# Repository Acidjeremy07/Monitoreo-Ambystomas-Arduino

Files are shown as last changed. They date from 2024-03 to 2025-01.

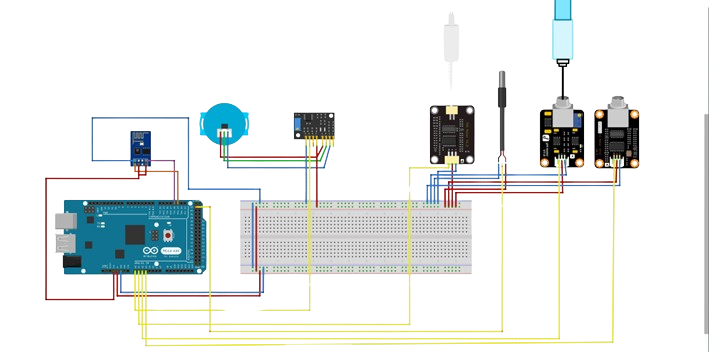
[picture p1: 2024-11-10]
Expo TT1/PNG de reporte técnico/PNG esquemático fritzing.png

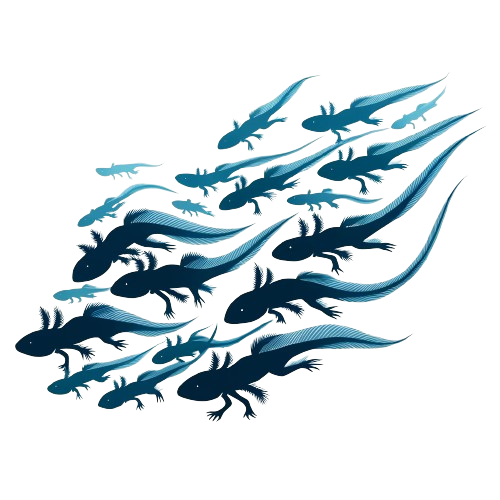
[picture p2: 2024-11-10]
Expo TT1/PNG Ajolotes/Ajolotes Adultos.png

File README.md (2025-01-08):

# Monitoreo Ambystomas arduino
 TT de monitoreo de la especies ambystomas tomando en cuenta el monitoreo de la calidad del agua donde se encuentran de manera ex situ
 Dentro del presente repositorio tenemos lo que es la forma de calibrar cada sensor así como la forma de usarlo de manera 
 individual, esto esta organizado por cada sensor de tal manera que se puede hayar cada código del sensor por carpeta con su nombre
 correspondiente

 Se incluye los primeros diseños de PCB para la conexión entre el arduino mega, esp01 y los sensores en la carpeta PCB

 Dentro de Datasheet's se incluye la hoja de datos de cada sensor y una referencia de conexión con el esp01

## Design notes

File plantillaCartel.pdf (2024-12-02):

Introducción (incluye planteamiento del problema, hipótesis y justificación)
El presente trabajo muestra la implementación de un sistema de monitoreo de la calidad del agua en ajolotarios dedicados a la conservación ex-situ de especies del género Ambystoma, en peligro de extinción o bajo protección especial (PROCER, 2018). El sistema cuantifica el valor de los parámetros esenciales para la supervivencia de los ajolotes como lo es el oxígeno disuelto y, si alguno alcanza niveles perjudiciales, notifica a los responsables mediante dispositivos móviles para una respuesta inmediata. Además de incluir un sistema web para el registro que se lleva cada treinta minutos y en caso de una alerta sea aproximadamente al cambio en el ajolotario , almacenamiento histórico de datos y la visualización e interpretación de los datos crudos, ya que esto complementaría y mejoraría la toma de decisiones en un ajolotario.

Materiales y métodos
Para el desarrollo del sistema de monitoreo de la calidad del agua en los ecosistemas del ajolote, se empleará una tarjeta Arduino Mega 2560 conectada a varios sensores que miden diferentes parámetros de calidad del agua. Los sensores utilizados son:
•Sensor de pH
•Sensor de Oxígeno Disuelto (mg/L)
•Sensor de Temperatura (°C)
•Sensor de Sólidos Disueltos Totales (TDS, ppm
•Sensor de Sólidos Suspendidos Totales (TSS, NTU)
La tarjeta Arduino se conectará a un módulo Wi-Fi ESP-01, que permitirá el envío de datos a la nube mediante Azure IoT. Para la arquitectura del sistema, se implementará un modelo de publicador-suscriptor, facilitando la comunicación entre los dispositivos de monitoreo y el servidor en la nube.
En el servidor, se usará un patrón de arquitectura de software de modelo-vistacontrolador (MVC), configurado como una API-REST para recibir y procesar los datos. La plataforma de alojamiento y administración de la base de datos será Vercel, donde se desplegará una aplicación web progresiva (PWA). Esta PWA permitirá visualizar los datos de calidad del agua tanto en dispositivos móviles como en equipos de cómputo, además de enviar alertas a través de WhatsApp en caso de detectar variaciones críticas en los parámetros monitoreados.

Referencias

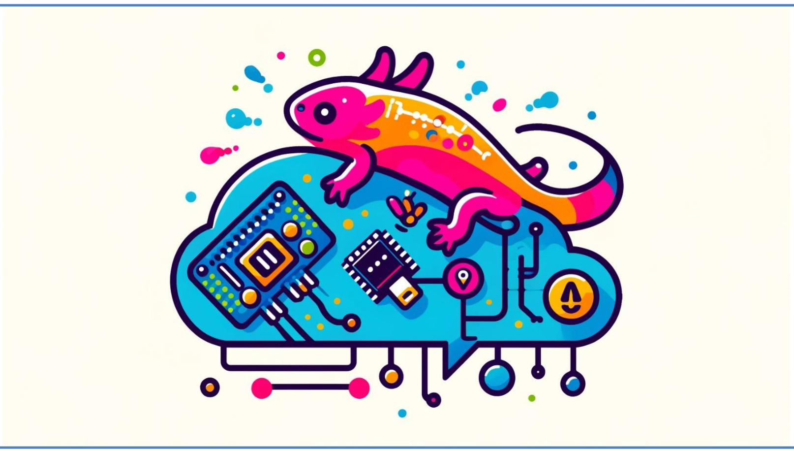
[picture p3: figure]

Comisión Nacional de Áreas Naturales Protegidas. (s/f).

Programa de Conservación de Especies en Riesgo (PROCER).

gob.mx. Recuperado el 12 de noviembre de 2024, de

https://www.gob.mx/conanp/acciones-y-

programas/programa-de-conservacion-de-especies-en-riesgo/ (https://www.gob.mx/conanp/acciones-y-programas/programa-de-conservacion-de-especies-en-riesgo/)

Objetivos
Implementar un sistema de gestión de datos que promueve la mejora continua para la conservación y bienestar de la especie Ambystoma mexicanum:
- Diseñar un dispositivo de obtención y envío de datos de los parámetros del ajolotario (Arduino MEGA 2560) .
- Construir un gabinete impermeable para PCB al que va conectado Arduino.
- Elaborar una aplicación web progresiva.
- Implementar un sistema de alertamiento en caso de detectar parámetros dañinos en el agua para los ajolotes.

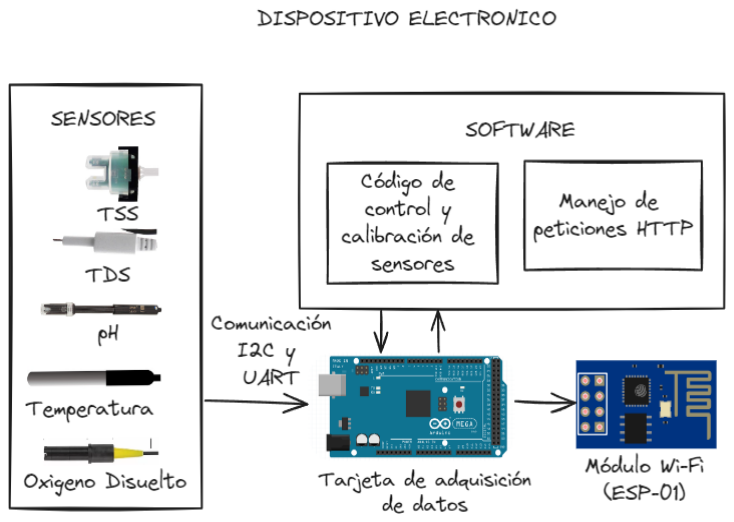
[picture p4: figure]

Resultados y conclusión
La implementación del sistema de monitoreo de la calidad del agua en el ajolotario Axolocali ha tenido efectos muy positivos sobre la conservación y manejo de los ajolotes en cautiverio. Al permitir la medición precisa de parámetros fisicoquímicos del agua, como el oxígeno disuelto, la temperatura, el pH, los sólidos disueltos y los sólidos suspendidos, el sistema evita la intervención directa en el entorno de los ajolotes, reduciendo así el estrés y el riesgo de alteraciones en su hábitat, lo cual es crucial para esta especie en peligro de extinción.
El registro y almacenamiento continuo de datos en la nube ha facilitado una interpretación más rápida y precisa de las condiciones del agua, lo que permite una toma de decisiones informada por parte de los cuidadores. Esto asegura una respuesta inmediata a cualquier cambio crítico en los parámetros, previniendo condiciones adversas para los ajolotes.

En consecuencia, el sistema ha demostrado ser una herramienta eficaz para la conservación ex-situ de especies del género Ambystoma. Dados los resultados exitosos en Axolocali, se proyecta la posibilidad de implementar este sistema en otros ajolotarios del país, contribuyendo a la protección y preservación de esta especie en riesgo a nivel nacional.

Representación

visual del sistema
de monitoreo .

## SISTEMA DE MONITOREO DE PARÁMETROS FISICOQUÍMICOS DE CALIDAD DEL AGUA PARA LA CONSERVACIÓN EX-SITU DE ESPECIES DE GÉNERO AMBYSTOMA

INSTITUTO POLITECNICO NACIONAL ESCUELA SUPERIOR DE CÓMPUTO BUCIO BARRERA OSCAR DANIEL, CAZARES CRUZ JEREMY SAJID, GUERRERO PÉREZ BRANDON JOSUÉ bguerrerop1600@alumno.ipn.mx

Tarjeta de adquisición de datos

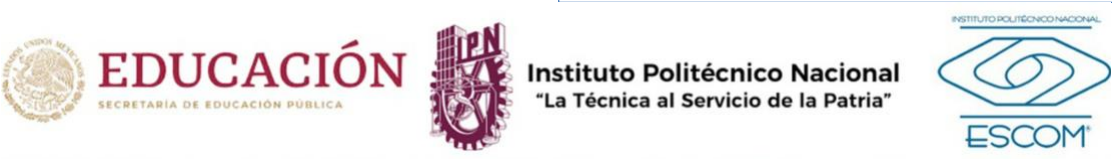
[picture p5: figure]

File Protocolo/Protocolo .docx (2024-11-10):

Prototipo para el monitoreo y alertamiento de la calidad del agua a través del internet de las cosas para conservación de especies ambystomas.

Trabajo Terminal No. 2024-B

Alumnos: Cazares Cruz Jeremy Sajid, *Guerrero Pérez Brandon Josué

Director: Morales Rodriguez Ursula Samantha

Email: bguerrerop1600@alumno.ipn.mx

Resumen - Se presenta el desarrollo de un ajolotario el cual contará con la innovación de mostrar la información de la calidad del agua en todo momento facilitando la comprensión de esta información a los clientes, esto con la finalidad de asegurar la supervivencia de los ajolotes manteniendo un hábitat óptimo para la conservación de estos.

Palabras clave - Sensores, calidad del agua, Internet de las cosas.

1. Introducción

La calidad del agua es fundamental para el bienestar de los ajolotes que son criaturas endémicas del Valle de México. Estos animales son especialmente sensibles a toxinas y cambios en su entorno acuático por lo que tener una mala calidad del agua afecta su salud, comportamiento y capacidad de regeneración.

Para abordar este desafío, la tecnología moderna, como el Internet de las Cosas (IoT), se ha convertido en una herramienta valiosa en la conservación de los ajolotes. Dispositivos inteligentes conectados a través de la IoT monitorean constantemente parámetros críticos como el pH, la temperatura y la salinidad del agua en los hábitats de los ajolotes. Estos dispositivos alertan a los cuidadores sobre cualquier desviación de los niveles óptimos y, en algunos casos, pueden ajustar automáticamente las condiciones para mantener un ambiente saludable.

Por ejemplo, sensores instalados en laboratorios de investigación o en hogares de entusiastas pueden enviar datos en tiempo real a aplicaciones móviles o plataformas en línea. Esto asegura un monitoreo constante y permite una respuesta inmediata ante cualquier problema, garantizando así la salud de los ajolotes.

La aplicación de la IoT en la conservación de ajolotes es un ejemplo de cómo la tecnología puede ser utilizada para proteger la biodiversidad y preservar especies en peligro de extinción. Esta combinación de prácticas tradicionales de cuidado con innovaciones del siglo XXI demuestra cómo podemos aprovechar la tecnología para proteger a estas fascinantes criaturas y su frágil hábitat.

A pesar de contar con el internet de las cosas, en el ámbito del cuidado de los animales acuáticos no siempre se visualiza el panorama completo, es decir que no se toman en cuenta todos los factores que favorecen a la supervivencia de los animales acuáticos, un ejemplo de esto es que casi no hay empresas que midan el oxígeno disuelto que hay en el agua.

En la siguiente tabla se colocan algunas empresas que si llevan a cabo el cuidado de hábitats de animales acuáticos:

EMPRESA | CARACTERÍSTICAS
HANNA instruments | Cuentan con sistemas embebidos listos para mostrar con que calidad cuenta el agua (en sus diferentes parámetros) con solo tener una muestra de esta.
Loxone | Ofrecen un acuario automático, el cual controlará la temperatura, verificará el nivel del agua, la iluminación y la alimentación de la pecera.

2. Objetivo

Implementar un prototipo para el monitoreo y alertemiento

2.1 Objetivos específicos

- Diseñar un circuito que integre sensores de pH y temperatura, capaces de detectar y registrar cambios con precisión.
- Diseñar un recinto o caja impermeable para albergar el circuito y asegurarse de que no haya ningún riesgo para los ajolotes.
- Programar un microcontrolador para leer los datos de los sensores y transmitirlos en tiempo real a una plataforma de IoT.
- Integrar conectividad al microcontrolador para transmitir los datos.
- Desarrollar una aplicación o interfaz web que permita visualizar en tiempo real los datos de pH y temperatura
- Establecer un sistema de notificaciones que alerte al usuario cuando la temperatura esté fuera del rango de 14°C a 20°C.
- Configurar alertas si el pH detectado si se desvía significativamente del valor aceptable.
3. Justificación

El proyecto de desarrollar un medidor de pH y temperatura para el agua en un hábitat de ajolotes es de suma importancia. Los ajolotes (Ambystoma mexicanum) son anfibios en peligro de extinción, y la conservación de su hábitat y bienestar es crucial para su supervivencia.

La monitorización constante y precisa del pH y la temperatura del agua es esencial para garantizar el bienestar de los ajolotes en cautiverio. Variaciones fuera de los parámetros óptimos pueden causar estrés, enfermedades e incluso la muerte de estos animales. La intervención manual y frecuente, que ha sido la práctica tradicional, es tediosa y puede llevar a periodos sin supervisión, lo que aumenta el riesgo para los ajolotes.

La incorporación de la tecnología de Internet de las Cosas (IoT) en este proyecto es fundamental. Al utilizar sensores conectados en tiempo real a plataformas digitales, se asegura un monitoreo continuo y se reciben alertas inmediatas en caso de problemas en las condiciones del agua. Esto no solo mejora el cuidado de los ajolotes, sino que también facilita la labor de los cuidadores y reduce el riesgo de errores humanos.

Además, este proyecto tiene un valor educativo significativo. Al proporcionar datos en tiempo real y una plataforma digital, se puede educar a cuidadores y entusiastas sobre la importancia crítica de mantener los niveles de pH y temperatura adecuados para los ajolotes. Al compartir esta información, se crea conciencia sobre la delicada situación de esta especie y se promueve su conservación.

4. Productos o Resultados esperados

Dispositivos de monitoreo IoT: Equipos diseñados específicamente para estanques y acuarios de ajolotes, capaces de rastrear condiciones como el pH, la temperatura y otros factores vitales del agua en tiempo real.

Aplicación web: Una plataforma digital accesible para los cuidadores que muestre de manera clara e intuitiva los datos recogidos por los dispositivos. Esta aplicación podría ofrecer gráficos de tendencias, alertas y recomendaciones basadas en las condiciones actuales.

Sistema de alerta automático: Un sistema que notifique de manera inmediata a los responsables cuando las condiciones del agua se desvíen de los parámetros ideales, garantizando intervenciones rápidas para salvaguardar el bienestar de los ajolotes.

Aplicación móvil: Una plataforma digital accesible desde cualquier dispositivo movil para los cuidadores que muestre de manera clara e intuitiva los datos recogidos por los dispositivos. Esta aplicación podría ofrecer gráficos de tendencias, alertas y recomendaciones basadas en las condiciones actuales.

5. Metodología
6. Cronograma
7. Referencias

[1] https://www.oracle.com/mx/internet-of-things/what-is-iot/

[2] https://cvsauces.com/cuidados-del-ajolote/

[3] https://www.badgermeter.com/es-us/monitoreo-de-la-calidad-del-agua/

[4] https://obtienearchivo.bcn.cl/obtienearchivo?id=repositorio/10221/23747/2/Calidad%20del%20Agua%20Final.pdf

[5] https://hannainst.com.mx/medidores-para-acuarios/

[6] Acuario automático - Ejemplos prácticos Loxone (https://www.loxone.com/eses/kb/acuario-automatico/)

8. Alumnos y Directores

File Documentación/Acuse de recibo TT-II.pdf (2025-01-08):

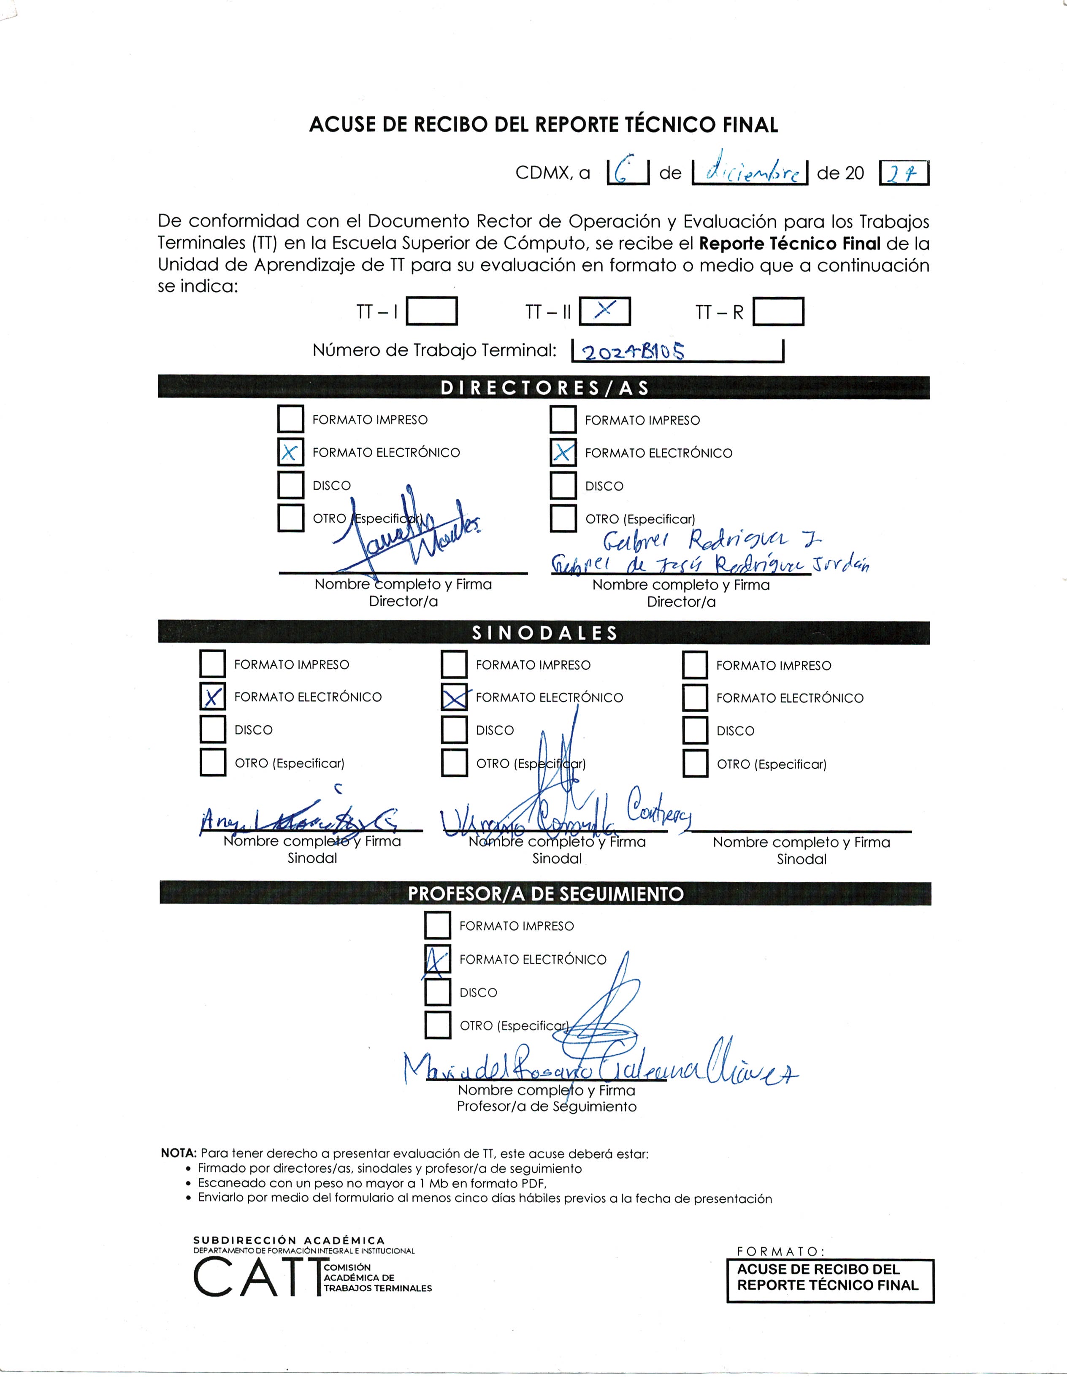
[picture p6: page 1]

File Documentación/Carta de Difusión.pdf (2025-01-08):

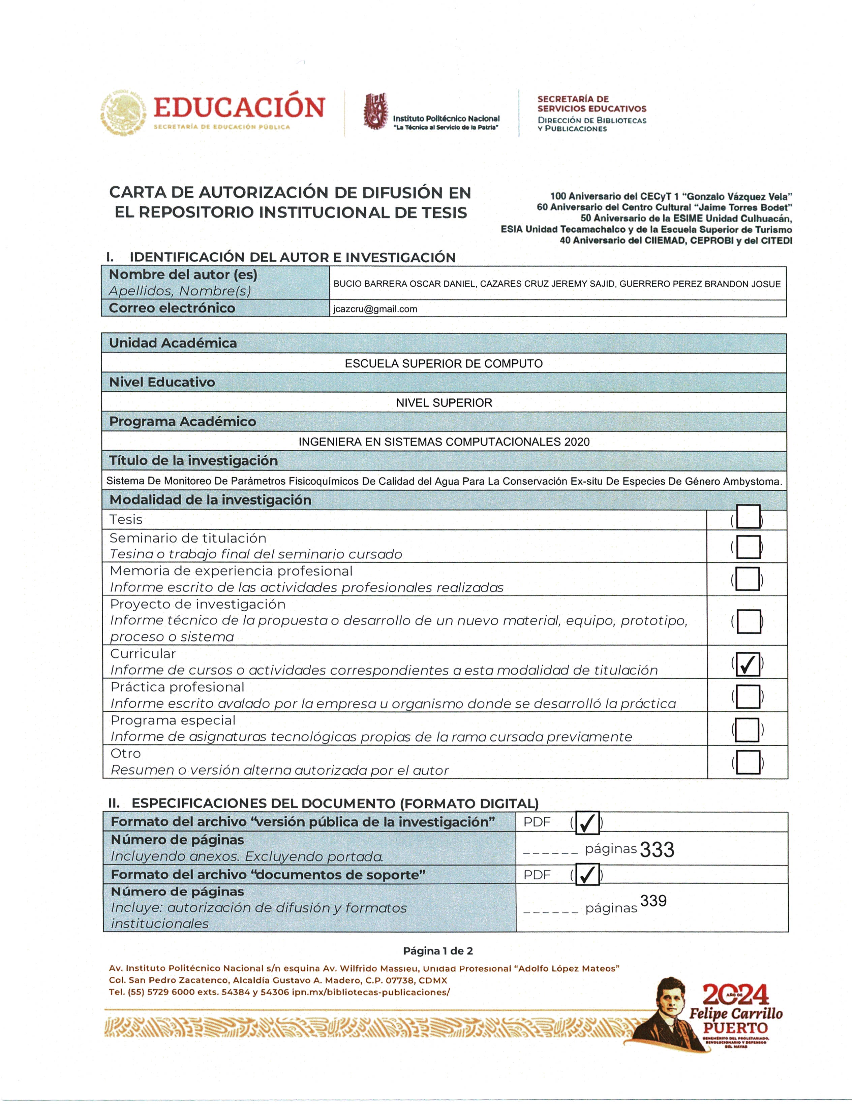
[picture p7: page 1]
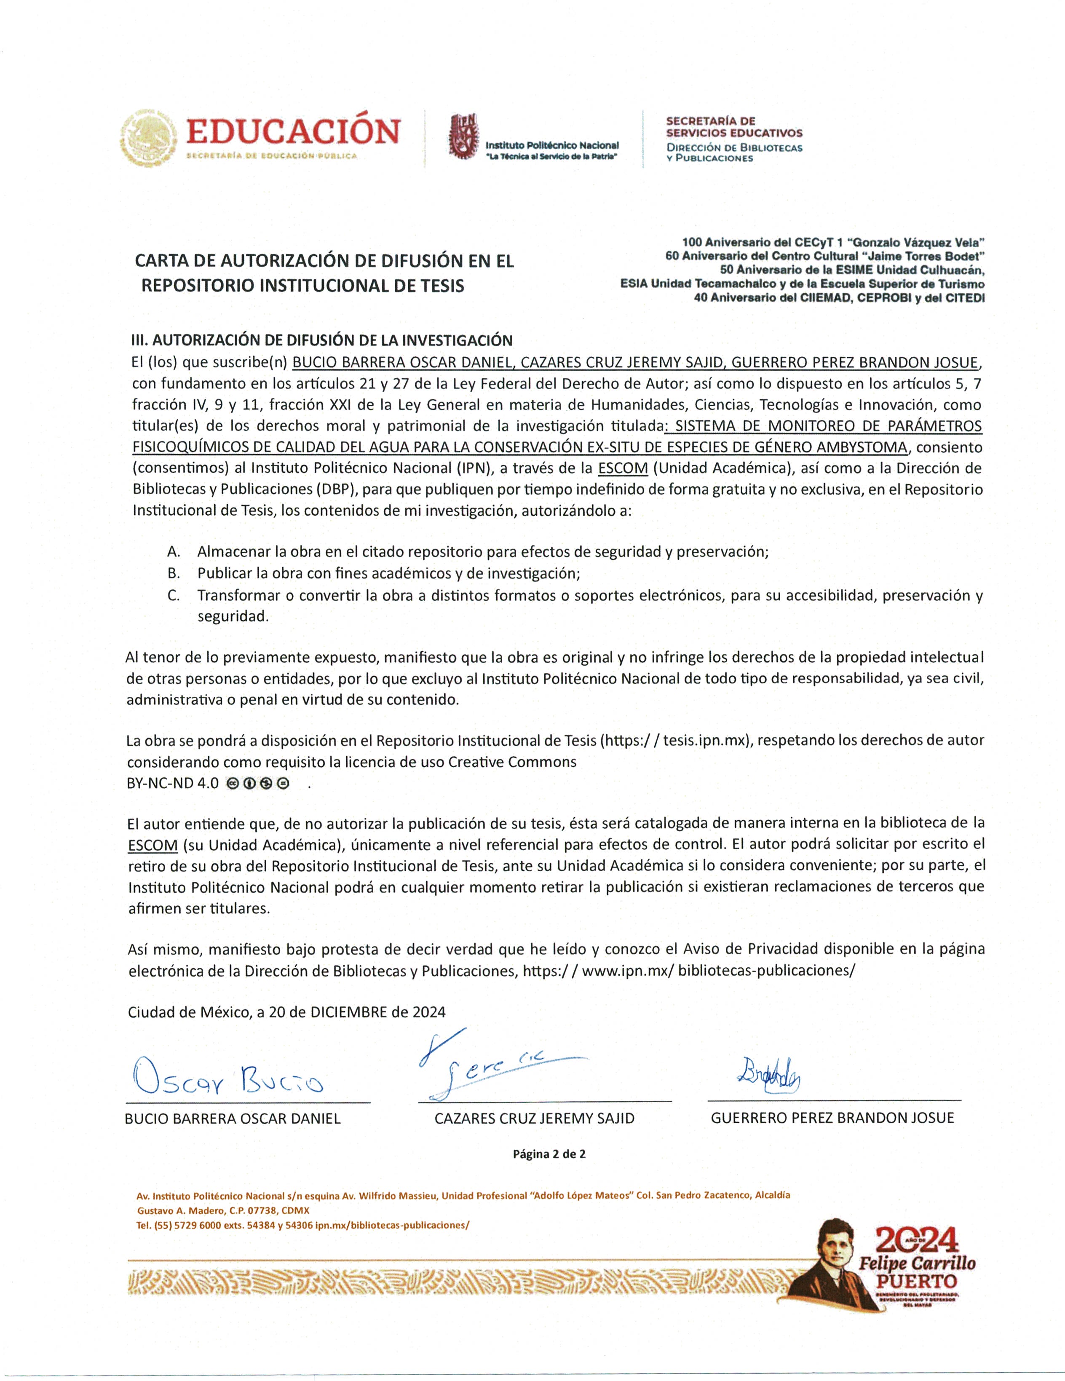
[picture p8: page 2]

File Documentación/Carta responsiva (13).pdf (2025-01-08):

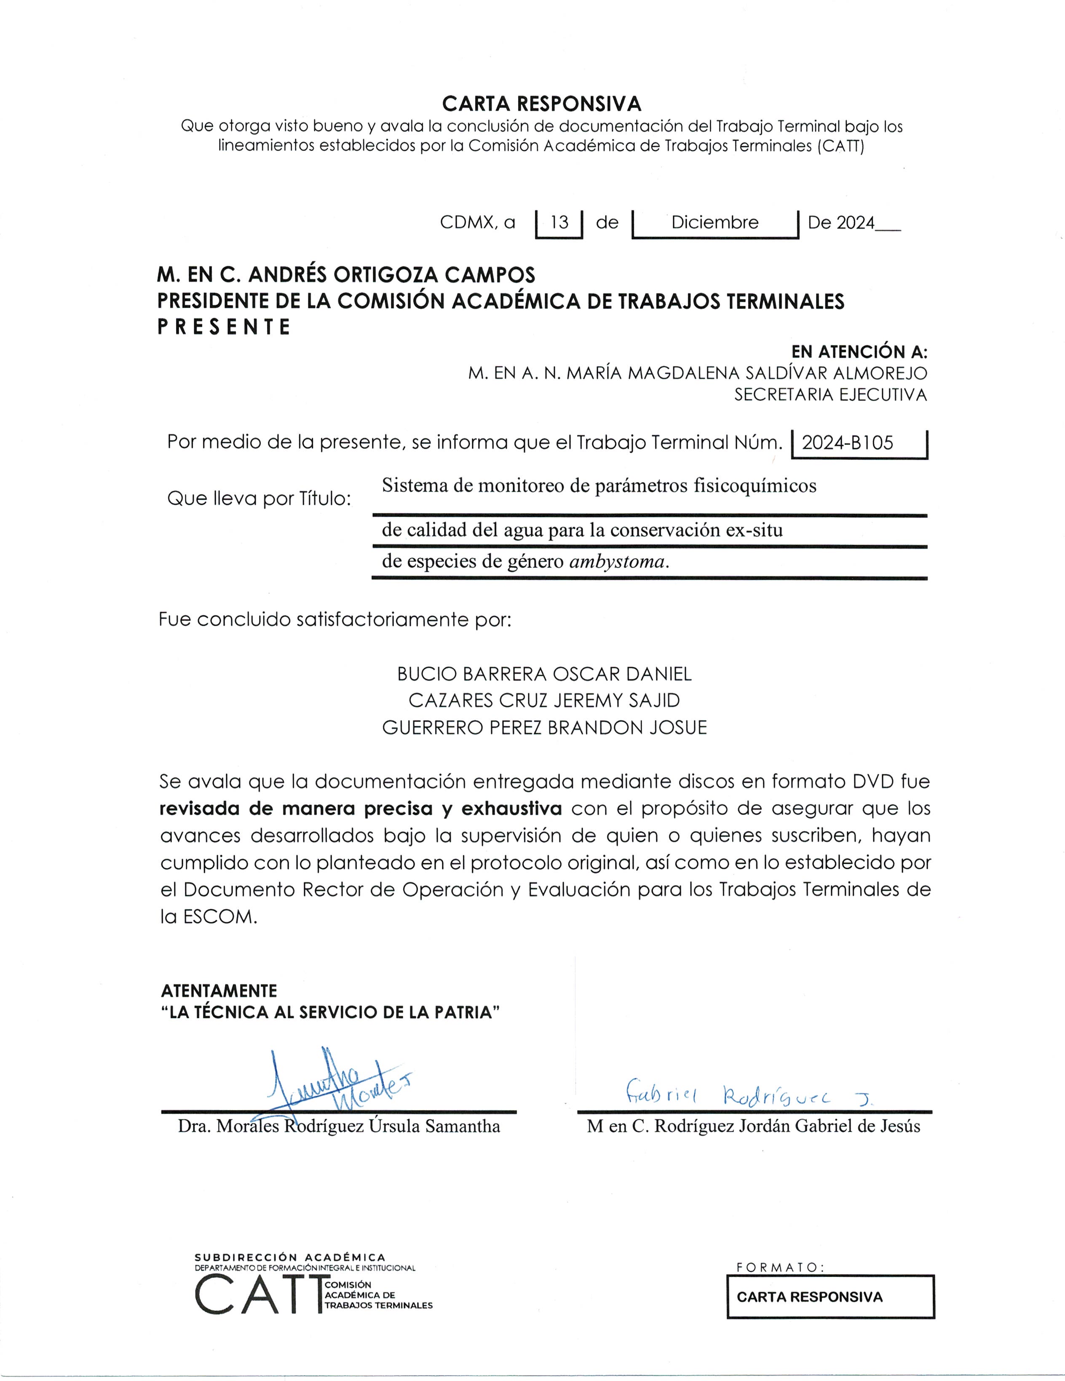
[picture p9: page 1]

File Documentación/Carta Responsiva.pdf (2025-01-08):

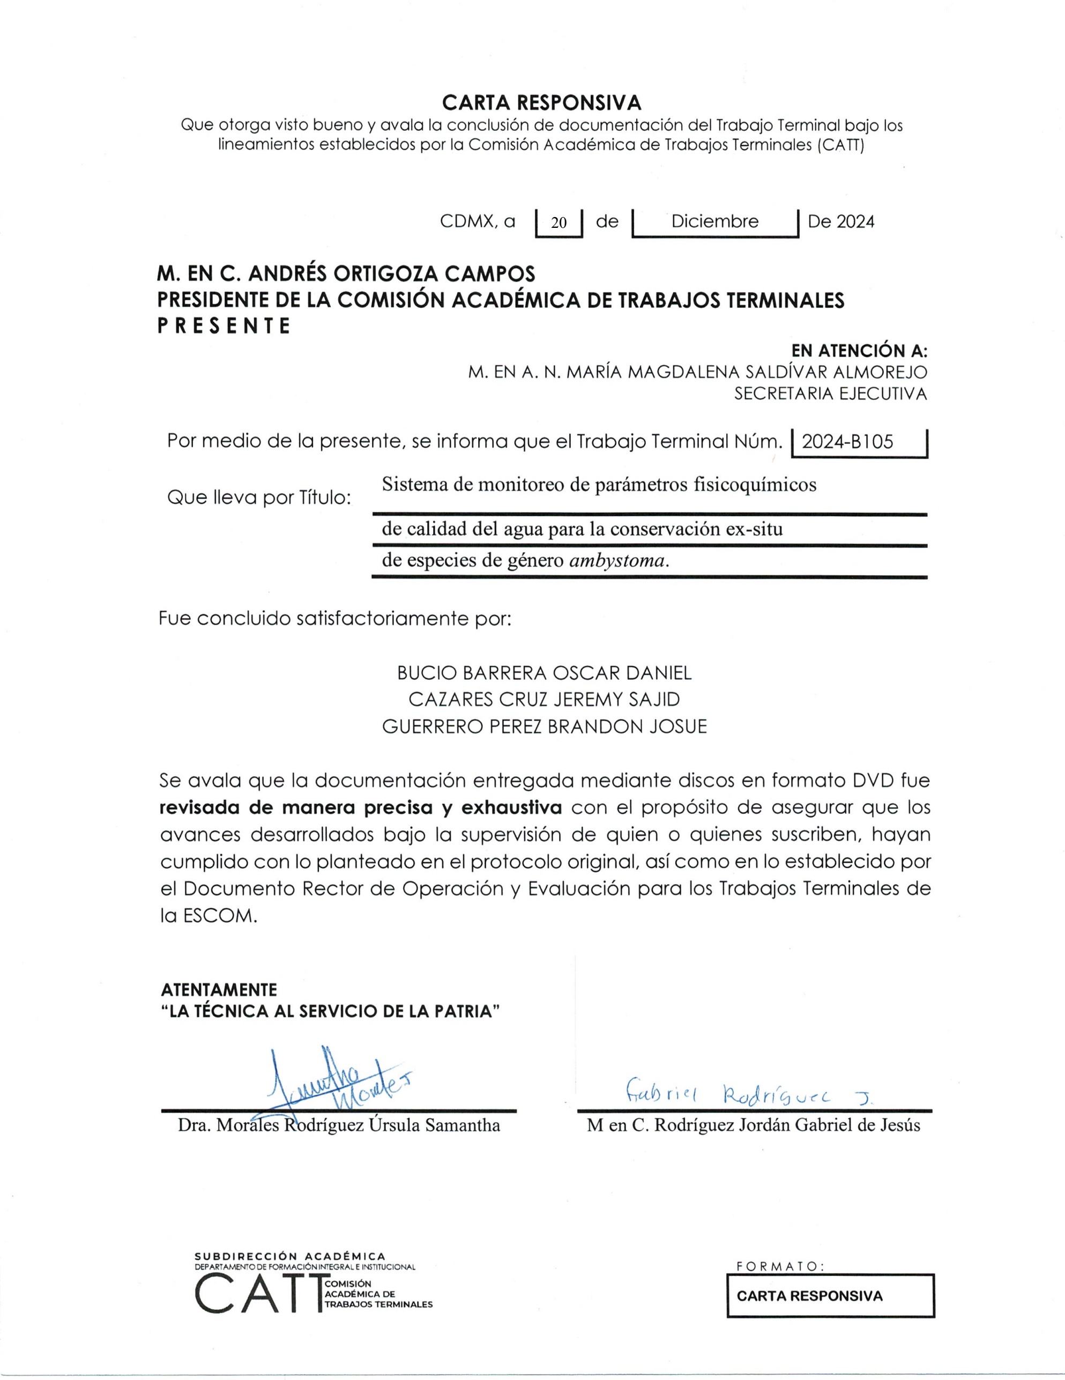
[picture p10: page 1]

20

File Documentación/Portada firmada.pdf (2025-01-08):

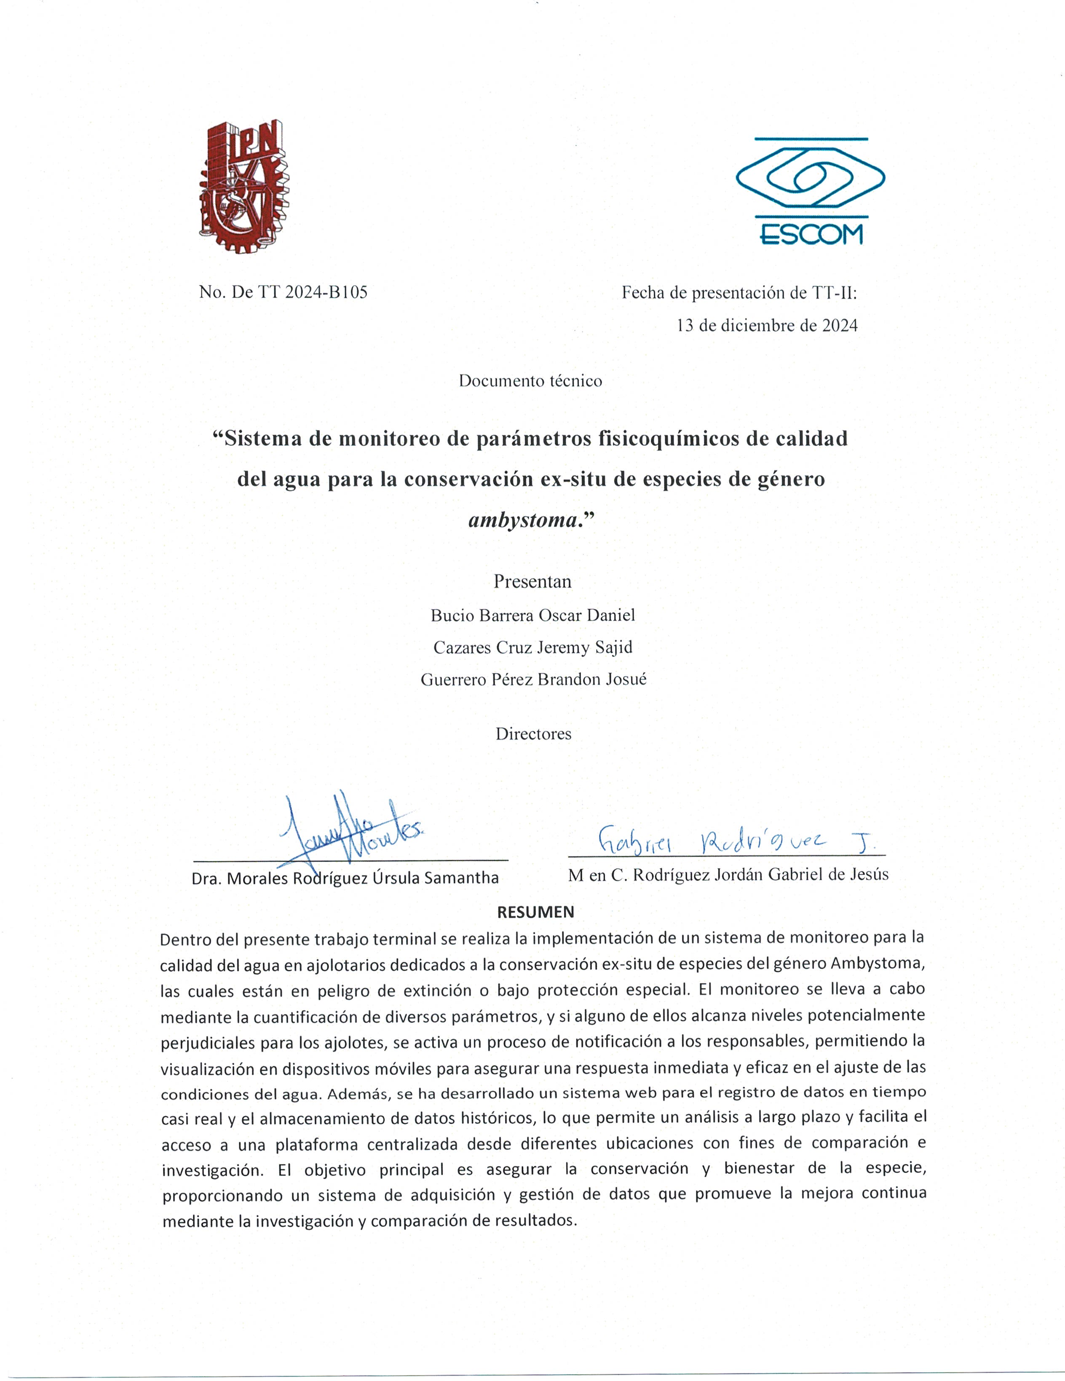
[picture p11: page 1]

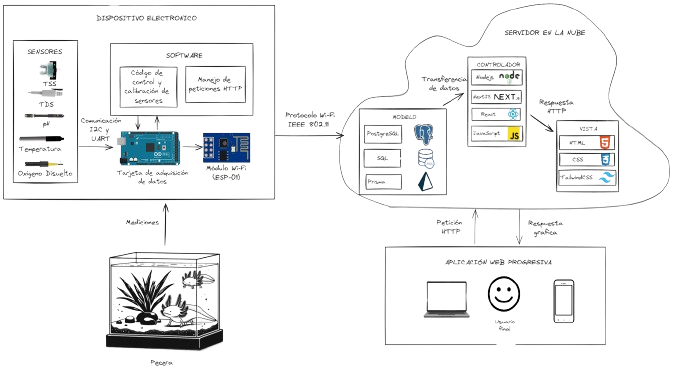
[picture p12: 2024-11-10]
Expo TT1/PNG de reporte técnico/PNG diagrama de bloques grande.png

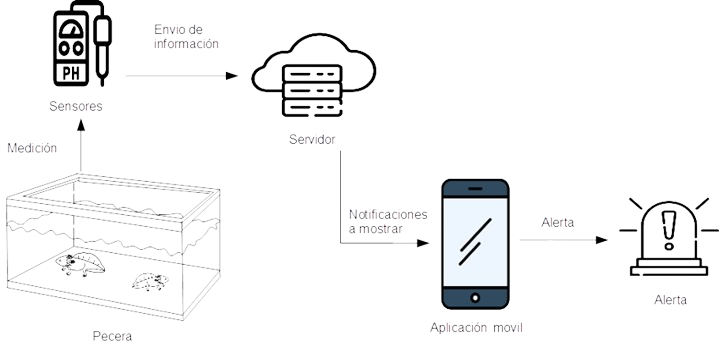
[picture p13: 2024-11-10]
Expo TT1/PNG de reporte técnico/PNG diagrama de bloques medio.png

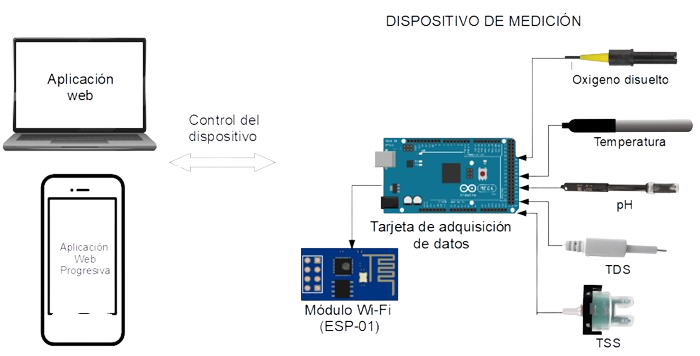
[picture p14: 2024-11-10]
Expo TT1/PNG de reporte técnico/Diagrama de bloques sencillo.png

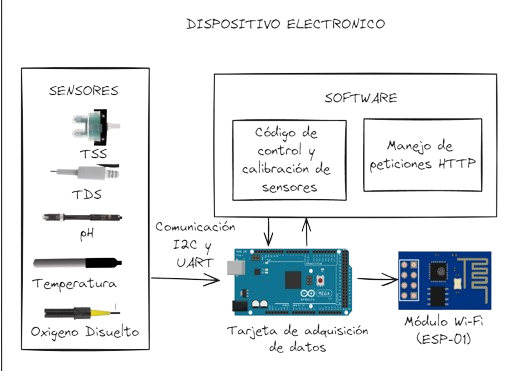
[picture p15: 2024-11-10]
Expo TT1/PNG de reporte técnico/Diagrama de bloques de adquisición de datos.png

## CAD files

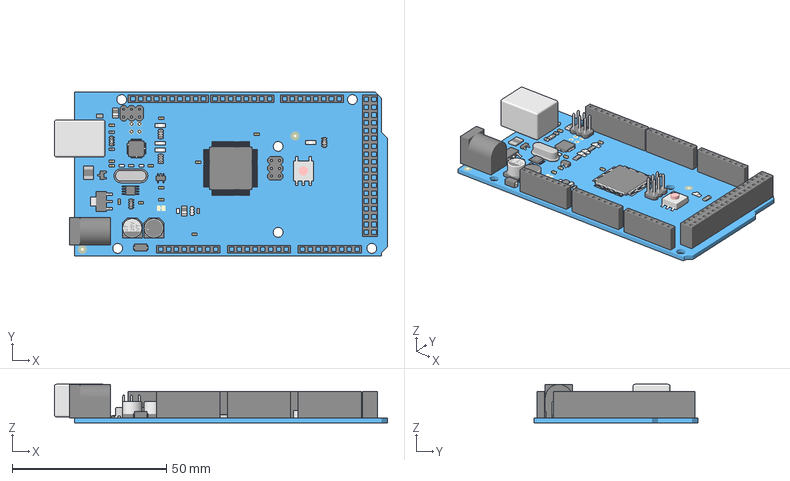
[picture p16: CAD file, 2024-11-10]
Expo TT1/Modelo 3D arduino mega/Arduino Mega 2560 - 3mf.3mf
108.1 x 53.3 x 12.5 mm
10-pin Header
100nF Capacitor (1)
100nF Capacitor (10)
100nF Capacitor (2)
100nF Capacitor (3)
100nF Capacitor (4)
100nF Capacitor (5)
100nF Capacitor (6)
100nF Capacitor (7)
100nF Capacitor (8)
100nF Capacitor (9)
100nF Capacitor
10k SMD Resistor Network Array (1)
10k SMD Resistor Network Array
16MHz Clock/Crystal
16MHz Resonator
18x2 Header
1M SMD Resistor 2
1M SMD Resistor
1k SMD Resistor Network Array (1) (1)
1k SMD Resistor Network Array (1)
22 Ohm SMD Resistor Network Array (1) (2)
22pF Capacitor 0603 (1)
22pF Capacitor 0603 (2)
22pF Capacitor 0603 (3)
3.3V Voltage Regulator LP2985
47 uF 25VDC Capacitor 1
47 uF 25VDC Capacitor 2
5V Voltage Regulator SOT-223
8-pin Header 1
8-pin Header 2
8-pin Header 3
8-pin Header 4
8-pin Header 5
A1SHB MOSFET
AREF Pins
ATmega16U2
ATmega2560
BRNCG0603MLC-05E Varistor (1)
BRNCG0603MLC-05E Varistor
Barrel Jack 2.1 x 5.5mm
CD1206-S01575 Diode 2
CD1206-S01575 Diode
Capacitor Gray
ICSP Pins
MP2307 Buck Regulator
On LED
PCB
PWM Capacitor
Pin 13 Onboard LED
Polyfuse
RVP Diode
Reset Button
Rx LED
Tx LED
USB-B Connector

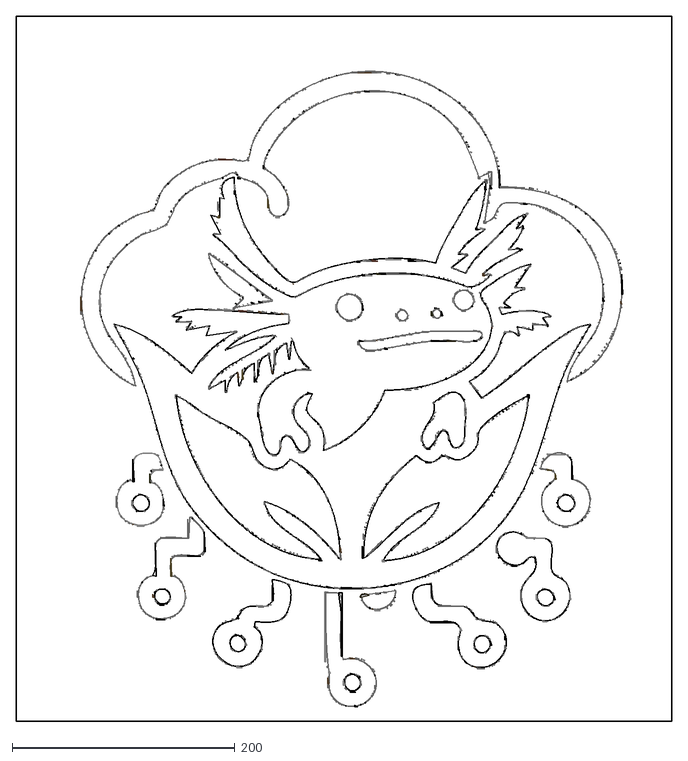
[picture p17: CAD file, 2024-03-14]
PCB/Logo/Logo vectorizado.dxf
589.0 x 633.0

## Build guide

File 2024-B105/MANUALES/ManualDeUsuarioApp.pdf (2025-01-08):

## Manual de usuario para aplicación del Sistema de monitoreo de parámetros fisicoquímicos de calidad del agua para la conservación ex-

situ de especies de género ambystoma.

Trabajo Terminal No. 2024-B105

### Alumnos: Cazares Cruz Jeremy Sajid, Bucio Barrera Oscar Daniel, *Guerrero Pérez Brandon Josué Directores: Morales Rodríguez Úrsula Samantha, Rodríguez Jordán Gabriel de Jesús Email: bguerrerop1600@alumno.ipn.mx

Resumen – AjoloApp es una herramienta integral diseñada para monitorear y gestionar parámetros fisicoquímicos del agua, contribuyendo a la conservación ex-situ de las especies del género Ambystoma. La aplicación ofrece un panel de control con vistas generales de instalaciones, tanques activos, ajolotes registrados y alertas críticas, permitiendo también la generación de informes en PDF. Entre sus principales funcionalidades, destaca la gestión de ajolotarios, tanques, sensores, usuarios y alertas, cada una con opciones para agregar, editar, visualizar y filtrar información. La aplicación soporta el registro de nuevos usuarios, el cambio de roles y la visualización detallada de mediciones recolectadas por sensores. Además, integra un sistema de generación de informes y una interfaz para la administración de dispositivos y parámetros asociados al monitoreo. Su diseño intuitivo y capacidad de personalización facilitan la toma de decisiones para asegurar un ambiente óptimo para la conservación de los ajolotes.

### 1. Introducción

AjoloApp es una herramienta integral diseñada para monitorear y gestionar los parámetros fisicoquímicos del agua con el objetivo de conservar de manera eficiente a las especies del género Ambystoma en condiciones ex-situ. Esta aplicación combina tecnología avanzada y un diseño intuitivo para garantizar el bienestar de estas especies mediante el control detallado de sus entornos. Desde el monitoreo de tanques hasta la gestión de alertas críticas, AjoloApp proporciona una solución integral para la conservación. Este manual tiene como objetivo guiarte en el uso de todas las funcionalidades que ofrece la aplicación, de manera que puedas aprovechar al máximo sus capacidades.

### 2. Inicio de Sesión

Para ingresar a AjoloApp, debes acceder a la página principal de inicio de sesión. En este espacio, se te solicitará que introduzcas tu correo electrónico registrado y la contraseña que hayas configurado previamente. Una vez completados estos datos, presiona el botón de "Iniciar Sesión" para acceder al sistema. Si aún no cuentas con una cuenta, la aplicación te redirige a un formulario de registro donde puedes crear un usuario. Durante este proceso, debes proporcionar información básica como tu nombre, apellidos, correo electrónico, número de teléfono y una contraseña. Es importante que aceptes los términos y condiciones para completar el registro. La contraseña debe cumplir con los requisitos mínimos de seguridad, como tener al menos ocho caracteres. Una vez registrado, puedes iniciar sesión y explorar las funcionalidades de la aplicación.

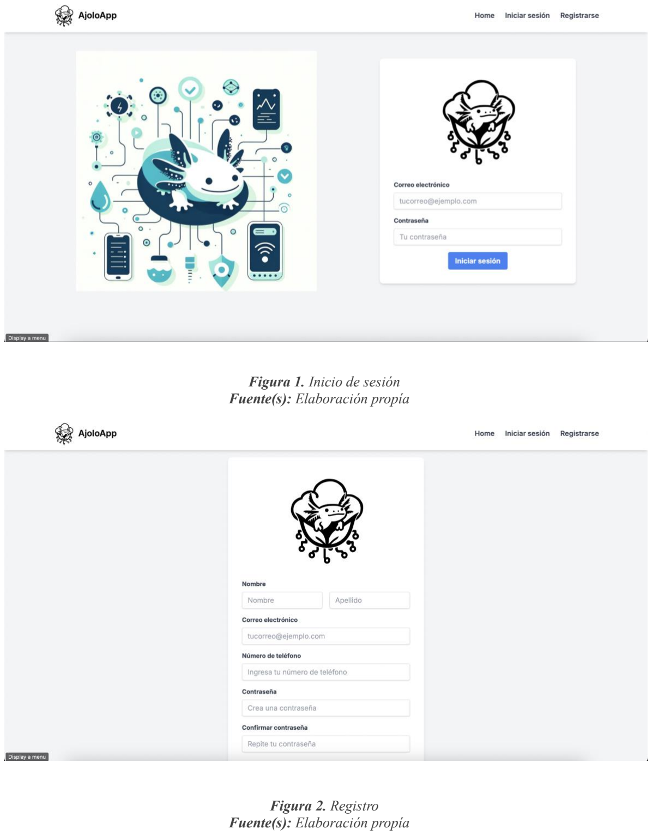
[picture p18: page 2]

Figura 1. Inicio de sesión Fuente(s): Elaboración propía

Figura 2. Registro
Fuente(s): Elaboración propía

### 3. Navegación Principal

La interfaz principal de AjoloApp está diseñada para ser intuitiva y eficiente. Al iniciar sesión, serás redirigido al panel principal, conocido como el Dashboard. Aquí, encontrarás un resumen de los datos más relevantes, incluyendo el estado general de las instalaciones, tanques activos, alertas críticas y el número de ajolotes registrados. Desde el menú principal, puedes acceder a diversas secciones de la aplicación, como la gestión de instalaciones, tanques, sensores, usuarios, alertas y mediciones. Cada sección está organizada para ofrecer información detallada y opciones de administración específicas, facilitando así el control de todas las áreas del sistema.

Figura 3. Navbar
Fuente(s): Elaboración propía

### 4. El Dashboard

El Dashboard es el corazón de AjoloApp. Esta sección proporciona una visión general de los elementos más importantes del sistema. En esta página, puedes ver un resumen de las instalaciones activas, los tanques que están operativos, el número total de ajolotes monitoreados y las alertas que requieren atención inmediata. También incluye herramientas adicionales, como la generación de informes personalizados en formato PDF. Esto es especialmente útil para registrar los datos históricos y utilizarlos en evaluaciones o análisis más profundos. Además, el Dashboard incluye un mapa interactivo que muestra las ubicaciones de las instalaciones, lo que te permite tener una referencia visual rápida y precisa de la distribución de los ajolotarios.

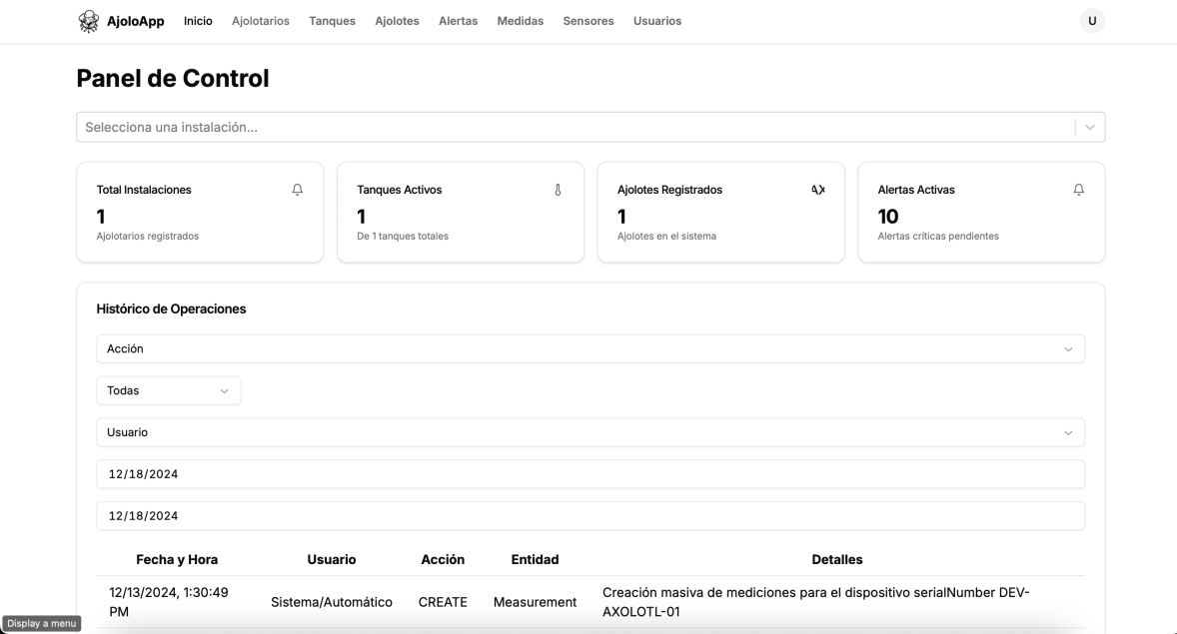
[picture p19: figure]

Figura 4. Dashboard primera parte Fuente(s): Elaboración propía

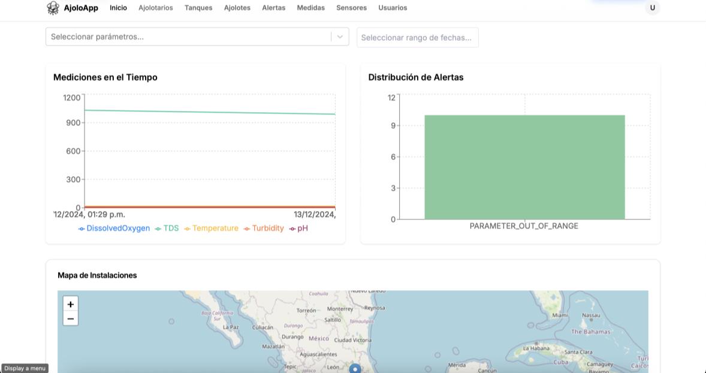
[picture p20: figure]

Figura 5. Dashboard segunda parte Fuente(s): Elaboración propía

### 5. Gestión de Ajolotarios

En la sección de gestión de ajolotarios, puedes administrar los ajolotarios de manera detallada. Cada ajolotario incluye información esencial como su nombre, ubicación, descripción, número de permiso y estado operativo. Puedes agregar nuevas instalaciones desde esta sección, asegurándote de proporcionar todos los datos requeridos. Además, es posible editar la información de los ajolotarios existentes para mantenerla actualizada. Los ajolotarios destacados también se muestran de forma prominente, permitiéndote ver información clave, como su ubicación y estado, de manera rápida y accesible.

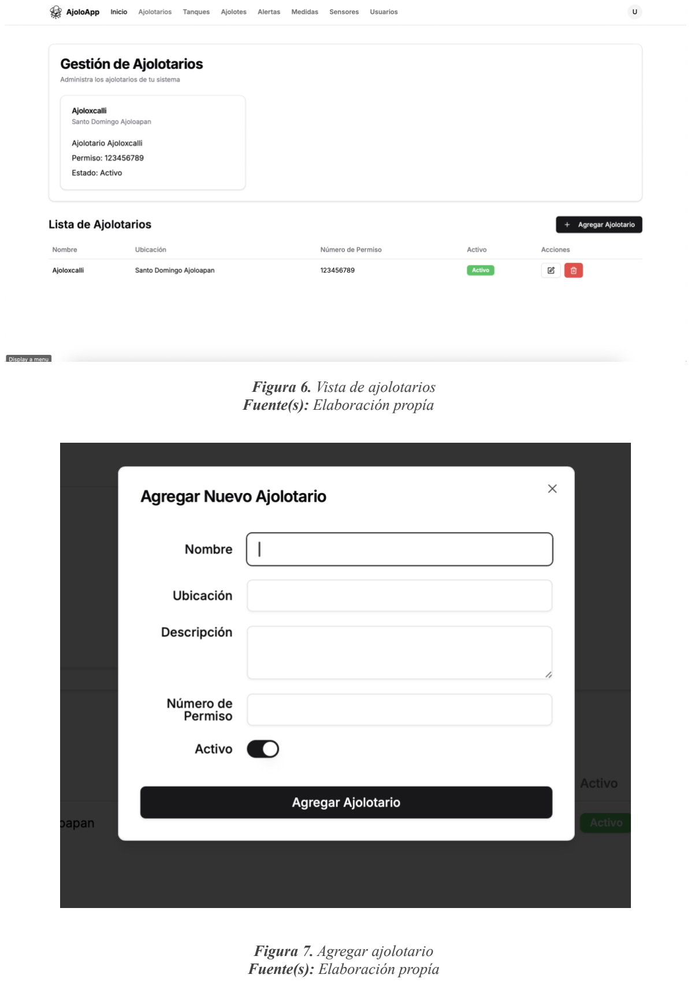
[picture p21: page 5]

Figura 6. Vista de ajolotarios Fuente(s): Elaboración propía

Figura 7. Agregar ajolotario Fuente(s): Elaboración propía

### 6. Gestión de Tanques

La gestión de tanques es una de las funcionalidades centrales de AjoloApp. Desde esta sección, puedes agregar nuevos tanques, modificar los existentes y asociarlos con ajolotarios específicos. Los tanques están configurados con parámetros clave como su capacidad, estado actual y observaciones adicionales. El sistema permite clasificar los tanques en estados como activo, en mantenimiento o en cuarentena, dependiendo de las necesidades de conservación. Además, puedes filtrar los tanques por ajolotarios para enfocarte en áreas específicas y realizar ajustes según las condiciones requeridas.

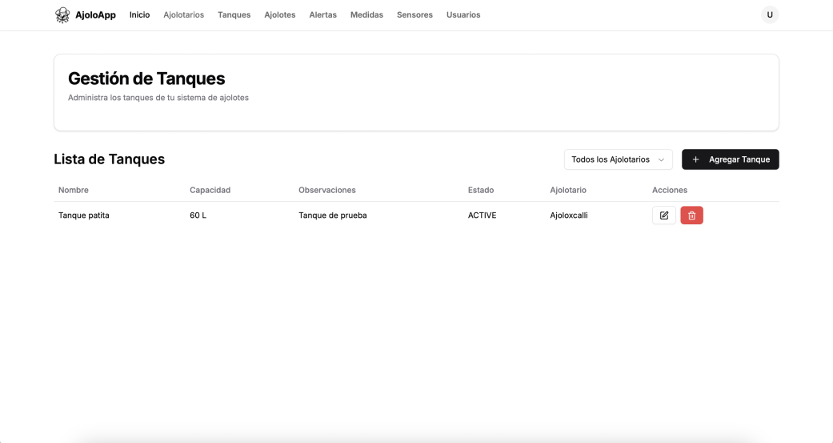
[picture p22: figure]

Figura 8. Vista de tanques Fuente(s): Elaboración propía

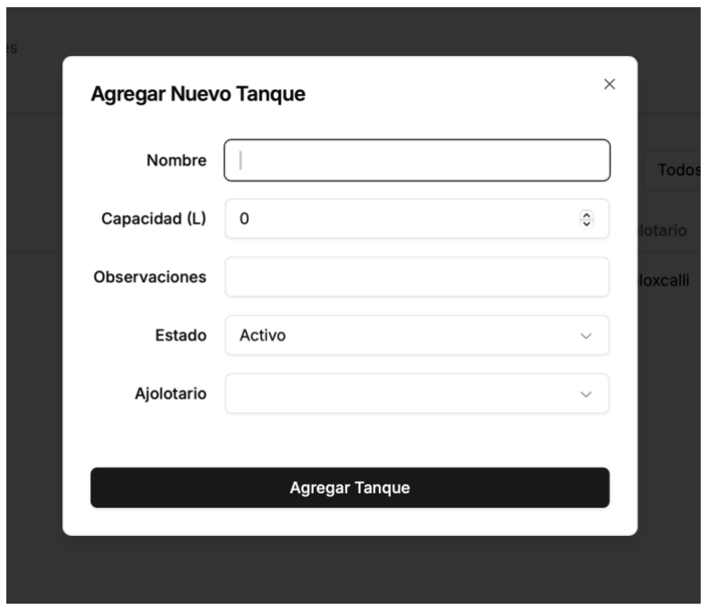
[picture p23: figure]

Figura 9. Agregar tanque
Fuente(s): Elaboración propía

### 7. Gestión de Sensores

Los sensores son una parte fundamental del sistema de monitoreo. En esta sección, puedes gestionar sensores individuales, asociándolos con dispositivos específicos o tanques. Cada sensor tiene características detalladas como modelo, número de serie, tipo y estado actual. Puedes agregar nuevos sensores al sistema, definir su configuración y realizar actualizaciones en caso de cambios en su estado o ubicación. Además, es posible gestionar tipos de sensores para personalizar el monitoreo, asegurando que cada tanque tenga los dispositivos adecuados para medir los parámetros más relevantes. La interfaz también permite verificar el estado de calibración de los sensores para garantizar mediciones precisas.

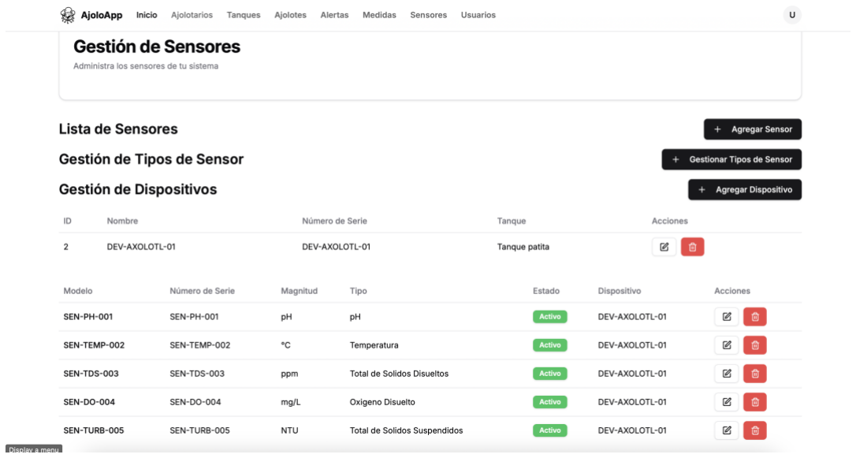
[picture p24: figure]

Figura 10. Vista de sensores Fuente(s): Elaboración propía

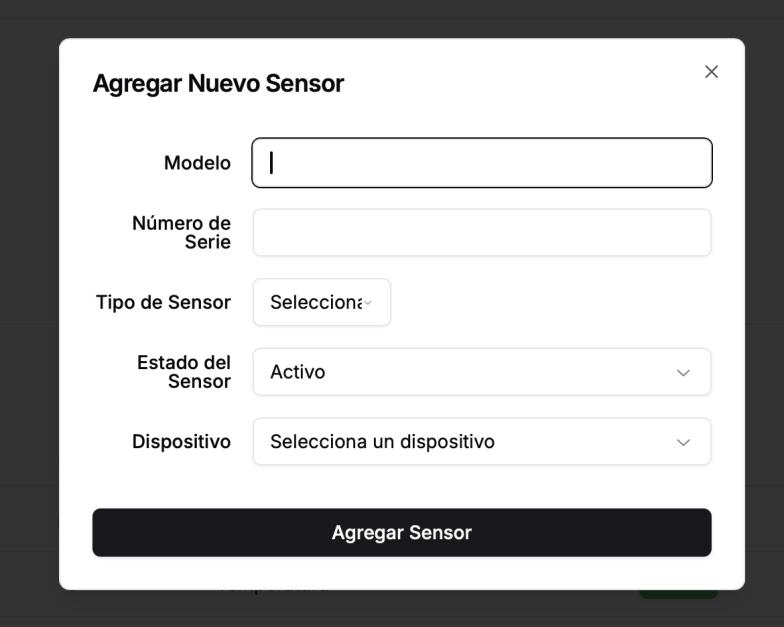
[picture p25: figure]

Figura 11. Agregar sensor
Fuente(s): Elaboración propía

### 8. Gestión de Usuarios

La gestión de usuarios es esencial para garantizar que cada persona tenga acceso únicamente a las funcionalidades que necesita. En esta sección, puedes ver una lista de todos los usuarios registrados en el sistema junto con su rol asignado. Los roles disponibles incluyen Super Admin, Admin de Ajolotario y Subscriptor. Como administrador, puedes modificar los roles directamente desde esta sección para otorgar o restringir permisos. Esto es especialmente útil para gestionar equipos grandes, asegurando que cada usuario tenga acceso a las herramientas necesarias según su responsabilidad.

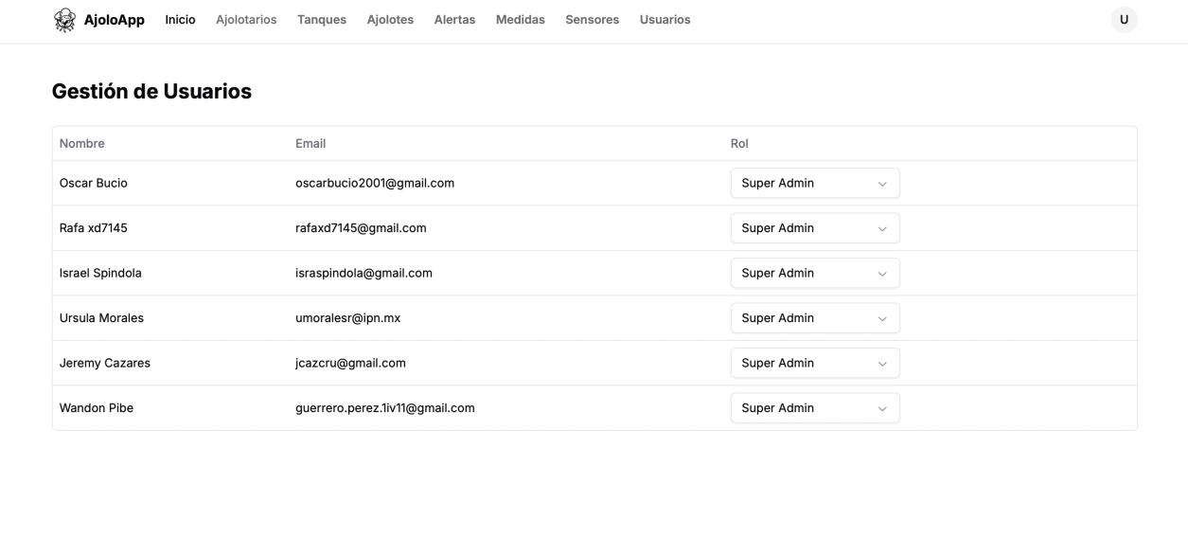
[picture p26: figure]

Figura 12. Vista de usuarios Fuente(s): Elaboración propía

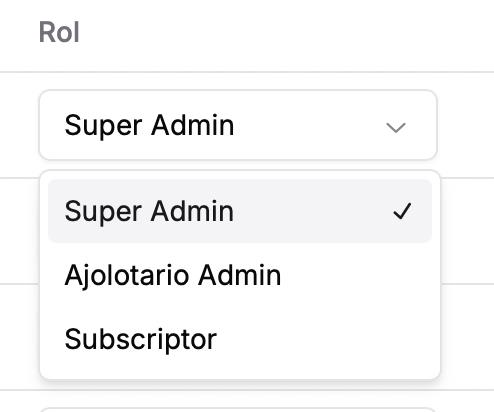
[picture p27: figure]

Figura 13. Gestión de usuarios Fuente(s): Elaboración propía

### 9. Alertas

La sección de alertas permite monitorear y administrar notificaciones críticas generadas por el sistema. Cada alerta contiene información detallada sobre su tipo, prioridad, estado y descripción. Desde esta sección, puedes filtrar alertas por parámetros como tipo, prioridad o estado, y priorizar las más urgentes. Las alertas se pueden actualizar según su resolución, y el sistema registra detalles como la fecha de resolución y el usuario encargado. Esto facilita el seguimiento de eventos importantes y asegura que las condiciones de los tanques sean óptimas en todo momento.

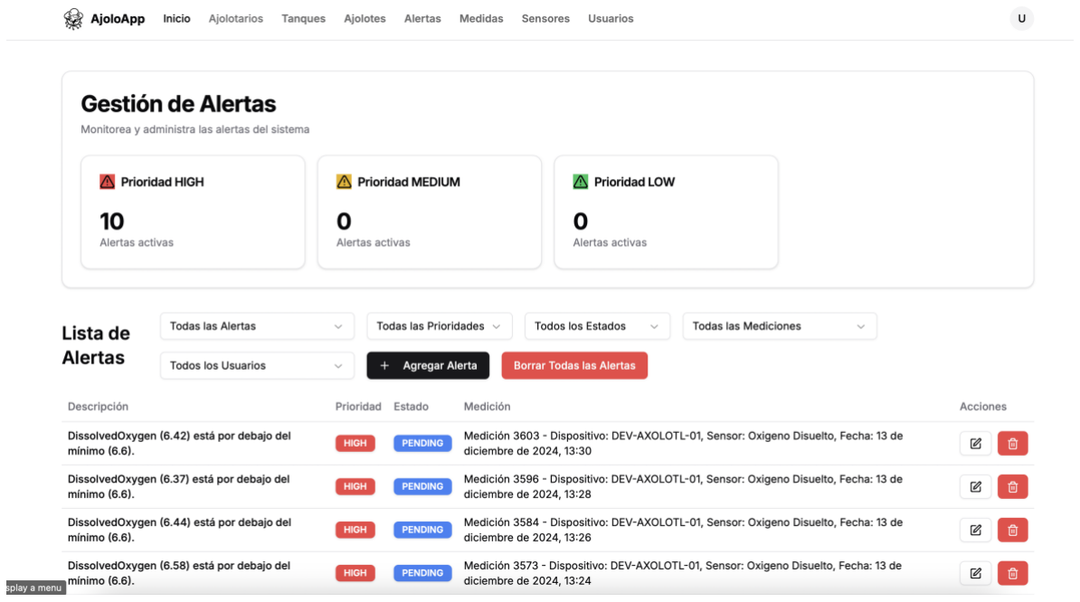
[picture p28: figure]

Figura 14. Vista de alertas Fuente(s): Elaboración propía

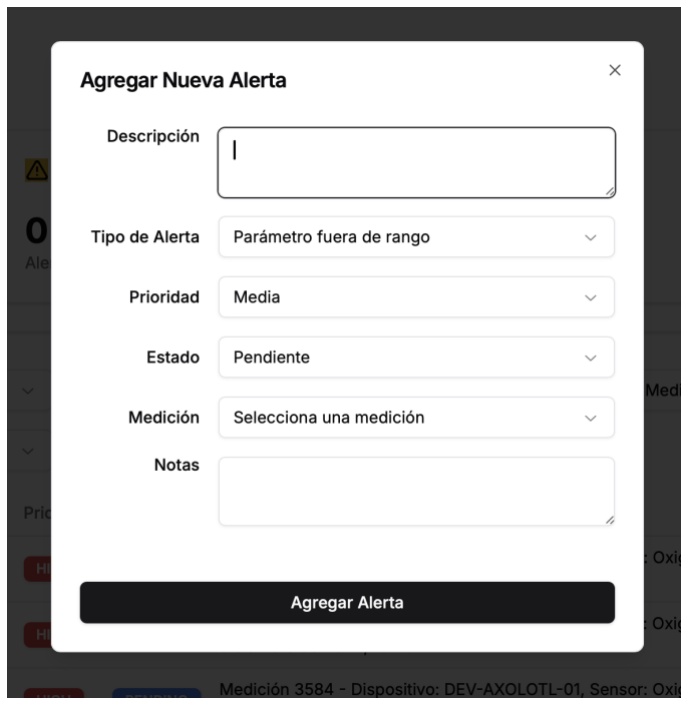
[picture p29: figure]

Figura 15. Agregar alerta
Fuente(s): Elaboración propía

### 10. Mediciones

La sección de mediciones está diseñada para monitorear los datos recolectados por los sensores. Aquí puedes visualizar mediciones asociadas con parámetros específicos, dispositivos y sensores. Además, es posible agregar nuevas mediciones, editarlas o eliminarlas según sea necesario. Cada medición incluye detalles como la fecha, hora, parámetros medidos y su validez. La gestión de mediciones también permite supervisar tendencias en los datos, ayudando a identificar posibles problemas antes de que se conviertan en riesgos mayores.

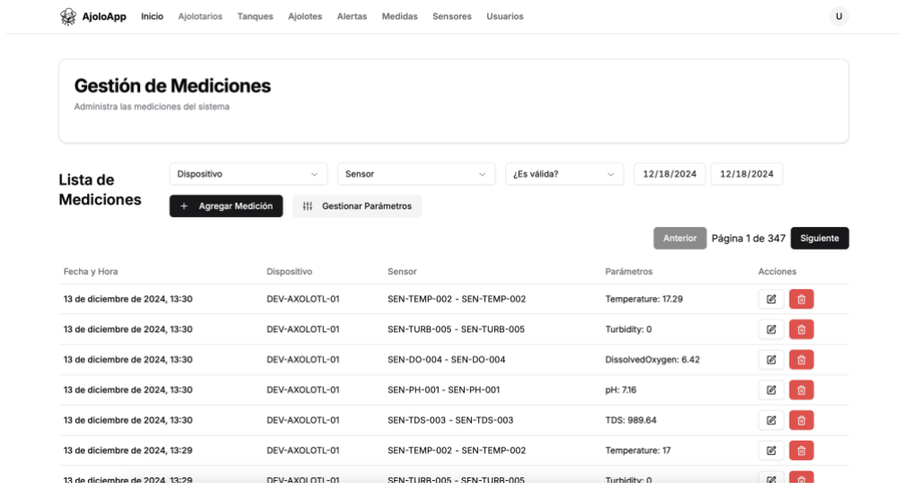
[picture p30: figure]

Figura 16. Vista de mediciones Fuente(s): Elaboración propía

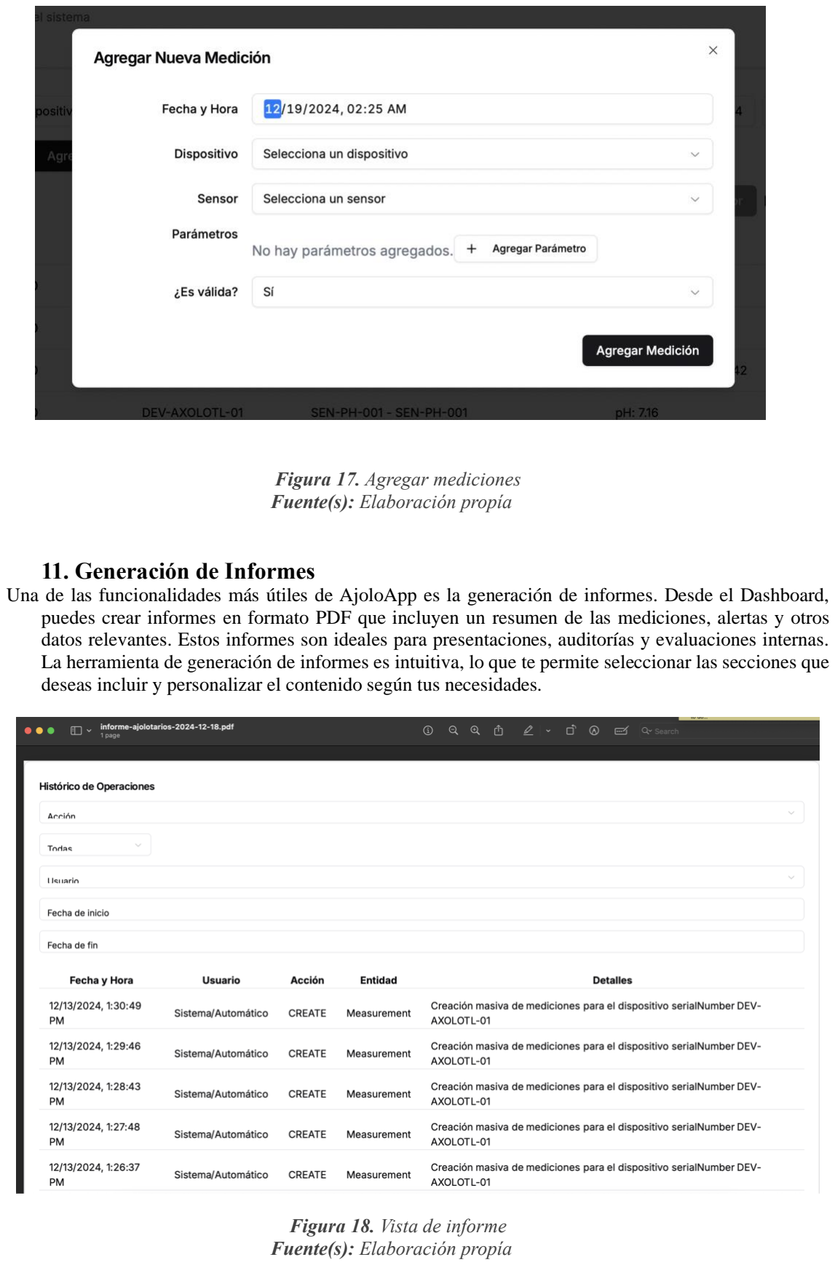
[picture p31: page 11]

Figura 17. Agregar mediciones Fuente(s): Elaboración propía

### 11. Generación de Informes

Una de las funcionalidades más útiles de AjoloApp es la generación de informes. Desde el Dashboard, puedes crear informes en formato PDF que incluyen un resumen de las mediciones, alertas y otros datos relevantes. Estos informes son ideales para presentaciones, auditorías y evaluaciones internas. La herramienta de generación de informes es intuitiva, lo que te permite seleccionar las secciones que deseas incluir y personalizar el contenido según tus necesidades.

Figura 18. Vista de informe Fuente(s): Elaboración propía

### 12. Configuración y Cierre de Sesión

En la configuración de usuario, puedes cambiar tu contraseña y actualizar tus datos personales. Para finalizar tu sesión, simplemente haz clic en el botón de "Logout". Esto te asegura que tu cuenta esté protegida, especialmente si estás utilizando un dispositivo compartido. El cierre de sesión es rápido y seguro, garantizando que tu información esté siempre protegida.

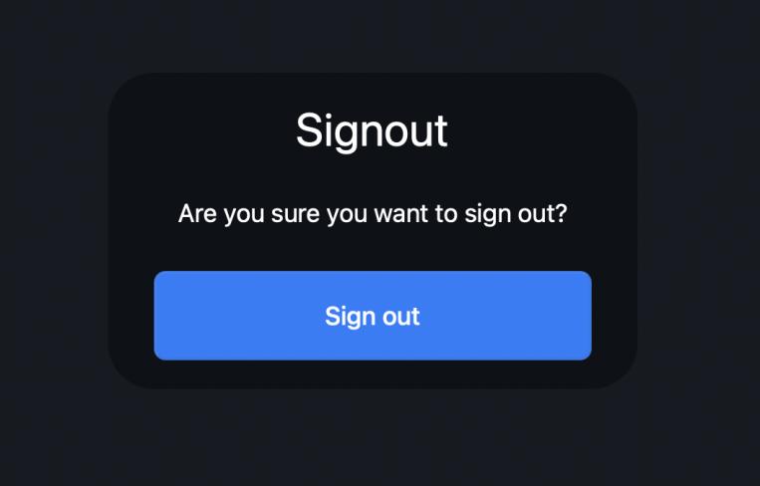
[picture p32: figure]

Figura 19. Cierre de sesión Fuente(s): Elaboración propía

### 13. Buenas Prácticas

Para garantizar el máximo rendimiento del sistema, es recomendable mantener los datos actualizados, especialmente en sensores y tanques. Monitorea regularmente las alertas y actúa de inmediato ante cualquier notificación crítica. Genera informes de manera periódica para analizar el desempeño del sistema y realizar ajustes según sea necesario. Finalmente, asegúrate de que todos los usuarios estén capacitados en el uso de la aplicación para garantizar una gestión eficiente y efectiva.

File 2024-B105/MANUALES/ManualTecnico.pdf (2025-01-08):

## Manual de usuario para aplicación del Sistema de monitoreo de parámetros fisicoquímicos de calidad del agua para la conservación ex-

situ de especies de género ambystoma.

Trabajo Terminal No. 2024-B105

### Alumnos: Cazares Cruz Jeremy Sajid, Bucio Barrera Oscar Daniel, *Guerrero Pérez Brandon Josué Directores: Morales Rodríguez Úrsula Samantha, Rodríguez Jordán Gabriel de Jesús Email: bguerrerop1600@alumno.ipn.mx

Resumen – AjoloApp es una herramienta integral diseñada para monitorear y gestionar parámetros fisicoquímicos del agua, contribuyendo a la conservación ex-situ de las especies del género Ambystoma. La aplicación ofrece un panel de control con vistas generales de instalaciones, tanques activos, ajolotes registrados y alertas críticas, permitiendo también la generación de informes en PDF. Entre sus principales funcionalidades, destaca la gestión de ajolotarios, tanques, sensores, usuarios y alertas, cada una con opciones para agregar, editar, visualizar y filtrar información. La aplicación soporta el registro de nuevos usuarios, el cambio de roles y la visualización detallada de mediciones recolectadas por sensores. Además, integra un sistema de generación de informes y una interfaz para la administración de dispositivos y parámetros asociados al monitoreo. Su diseño intuitivo y capacidad de personalización facilitan la toma de decisiones para asegurar un ambiente óptimo para la conservación de los ajolotes.

### 1. Introducción

AjoloApp es una aplicación web diseñada para el monitoreo y la gestión de parámetros fisicoquímicos del agua, enfocada en la conservación ex-situ de las especies del género Ambystoma. La aplicación proporciona una solución integral que combina tecnología de vanguardia con una interfaz intuitiva. Este documento tiene como objetivo describir detalladamente la arquitectura, configuración y componentes técnicos de AjoloApp, facilitando el mantenimiento, escalabilidad y extensión de la aplicación.

### 2. Tecnologías utilizadas

AjoloApp está construida utilizando una pila tecnológica moderna y robusta. En el frontend, se utiliza React junto con Next.js para gestionar el enrutamiento y el renderizado del lado del cliente y del servidor. Los componentes de interfaz están estilizados con Tailwind CSS, lo que permite una personalización rápida y eficiente del diseño. En el backend, se implementa Next.js con rutas API que interactúan con una base de datos PostgreSQL a través de Prisma ORM. La autenticación está gestionada mediante NextAuth, utilizando credenciales seguras. Además, se integran servicios externos como Telegram y WhatsApp para notificaciones en tiempo real, y jsPDF junto con html2canvas para la generación de informes PDF.

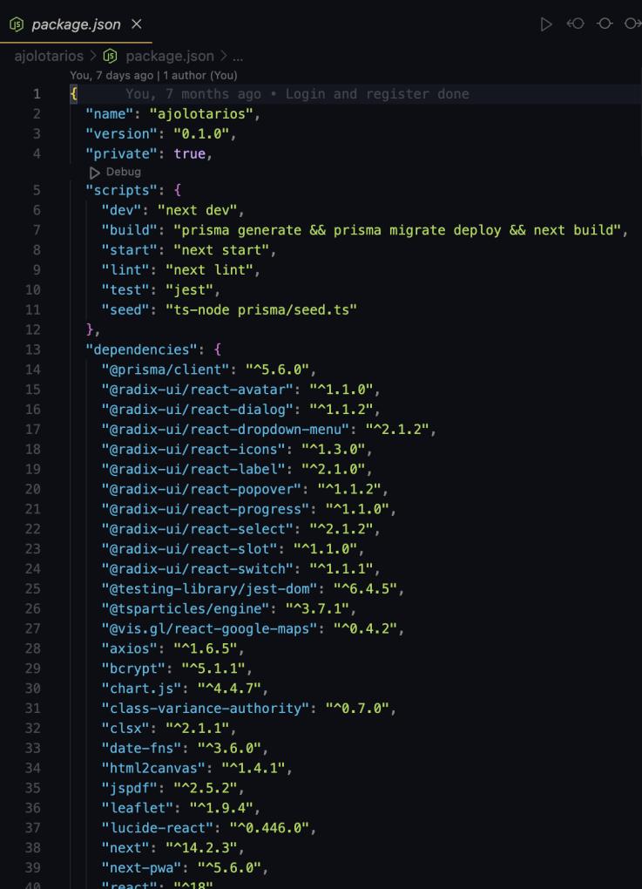
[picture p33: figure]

Figura 1. Tecnologías y librerias usadas Fuente(s): Elaboración propía

### 3. Estructura del proyecto

La organización del proyecto está diseñada para facilitar la navegación y el mantenimiento del código. Dentro de la carpeta principal del proyecto se encuentran las siguientes secciones clave. En la carpeta src/app, se alojan todas las páginas principales de la aplicación, como el Dashboard y las secciones de gestión. En la carpeta src/components, están disponibles componentes reutilizables como botones, formularios y tablas. Las rutas API se encuentran en la carpeta src/api y manejan la comunicación entre el frontend y el backend. Finalmente, el esquema de la base de datos está definido en la carpeta prisma, utilizando archivos .prisma para modelar las entidades y sus relaciones.

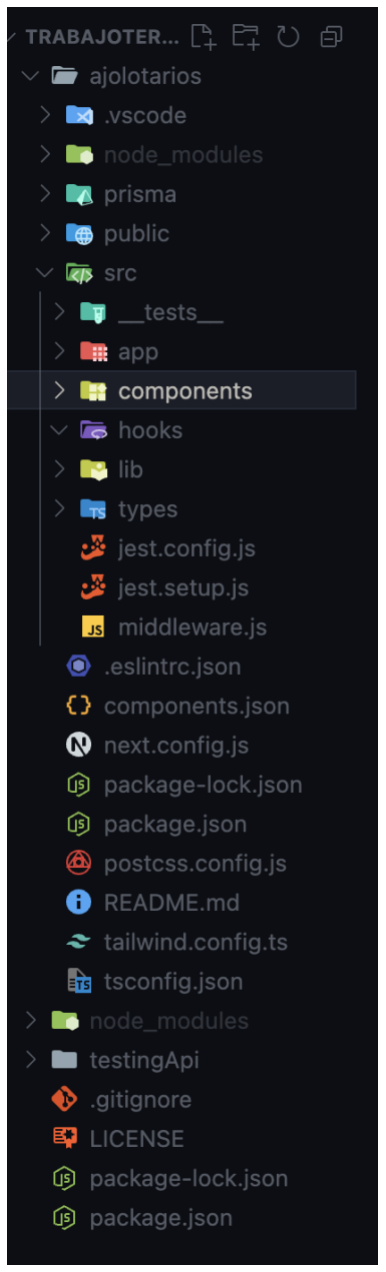
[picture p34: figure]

Figura 2. Estructura del proyecto Fuente(s): Elaboración propía

### 4. Base de datos

La base de datos de AjoloApp utiliza PostgreSQL, gestionada con Prisma ORM para garantizar eficiencia y flexibilidad. Las principales entidades incluyen User, que administra a los usuarios con atributos como nombre, correo electrónico, rol y contraseña encriptada. La entidad Ajolotary representa las instalaciones, almacenando información como su ubicación, descripción y estado operativo. Los tanques, definidos en la entidad Tank, están asociados a los ajolotarios y contienen detalles como capacidad y estado. Los sensores, descritos en la entidad Sensor, se vinculan a los tanques para monitorear parámetros específicos. Además, las mediciones y alertas son gestionadas a través de las entidades Measurement y Alert, que permiten almacenar los datos recolectados y generar notificaciones críticas.

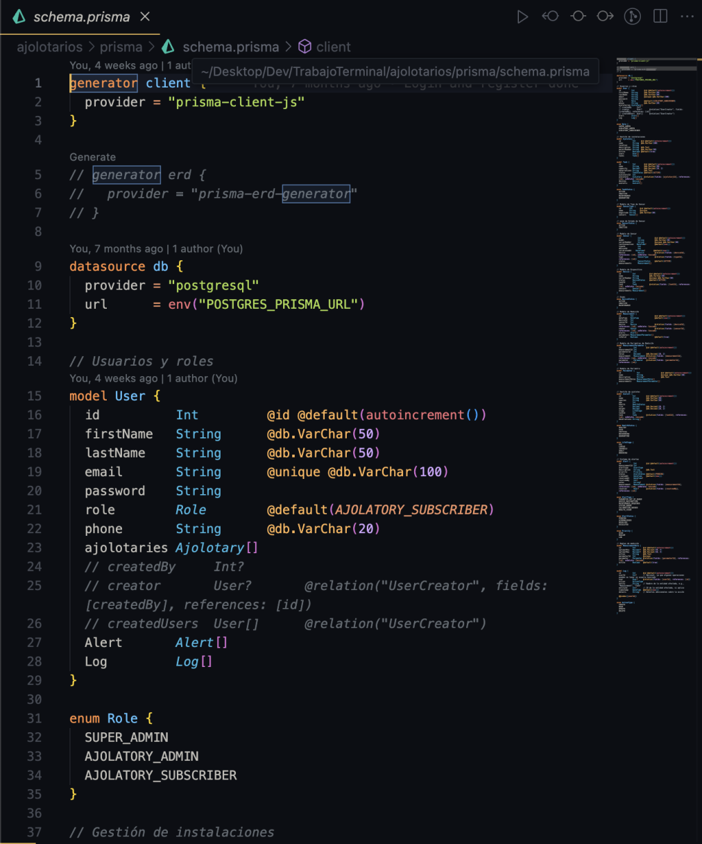
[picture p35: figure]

Figura 3. Esquema de DB en prisma Fuente(s): Elaboración propía

### 5. Funcionalidades del backend

El backend está diseñado con rutas API que proporcionan endpoints REST para cada entidad principal. Por ejemplo, la ruta /api/ajolotaries permite obtener o crear nuevos ajolotarios, mientras que /api/sensors/[id] se utiliza para actualizar o eliminar sensores específicos. Estas rutas están protegidas mediante middleware de autenticación, garantizando que solo los usuarios autorizados puedan acceder a ellas. Además, las notificaciones en tiempo real se implementan mediante integraciones con Telegram y WhatsApp. Estas funciones utilizan llamadas HTTP seguras para enviar mensajes de alerta directamente a los dispositivos móviles de los usuarios.

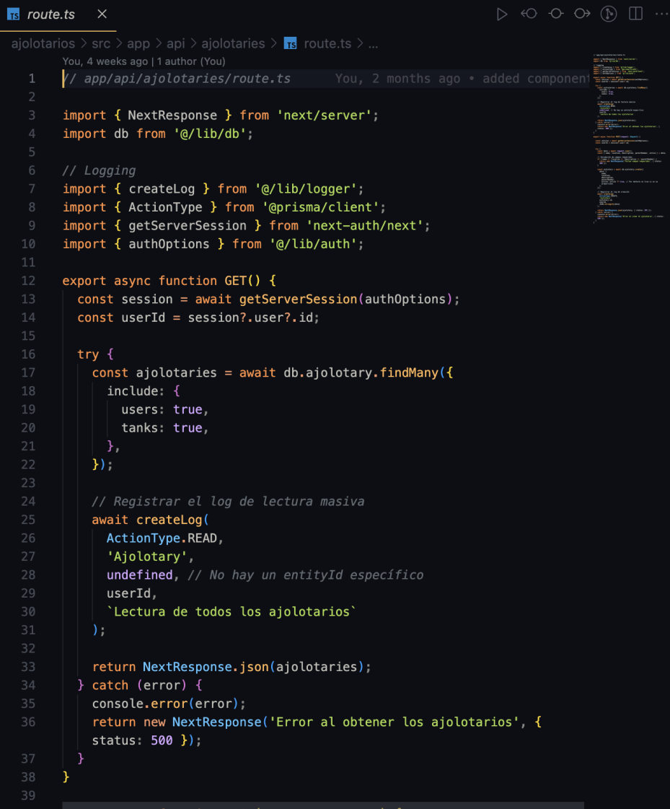
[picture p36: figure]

Figura 4. Ejemplo api route Fuente(s): Elaboración propía

### 6. Frontend

El frontend de AjoloApp está compuesto por páginas React que interactúan con las rutas API del backend. Cada página está diseñada para manejar la lógica de negocio correspondiente, incluyendo validaciones de formularios y actualización del estado. El Dashboard sirve como la interfaz principal, mostrando datos resumidos y herramientas de visualización como gráficas y mapas. Las secciones de gestión permiten a los usuarios agregar o editar información, mientras que los componentes personalizados aseguran un diseño consistente en toda la aplicación. Estos componentes incluyen botones, tarjetas y tablas que se pueden reutilizar en múltiples secciones.

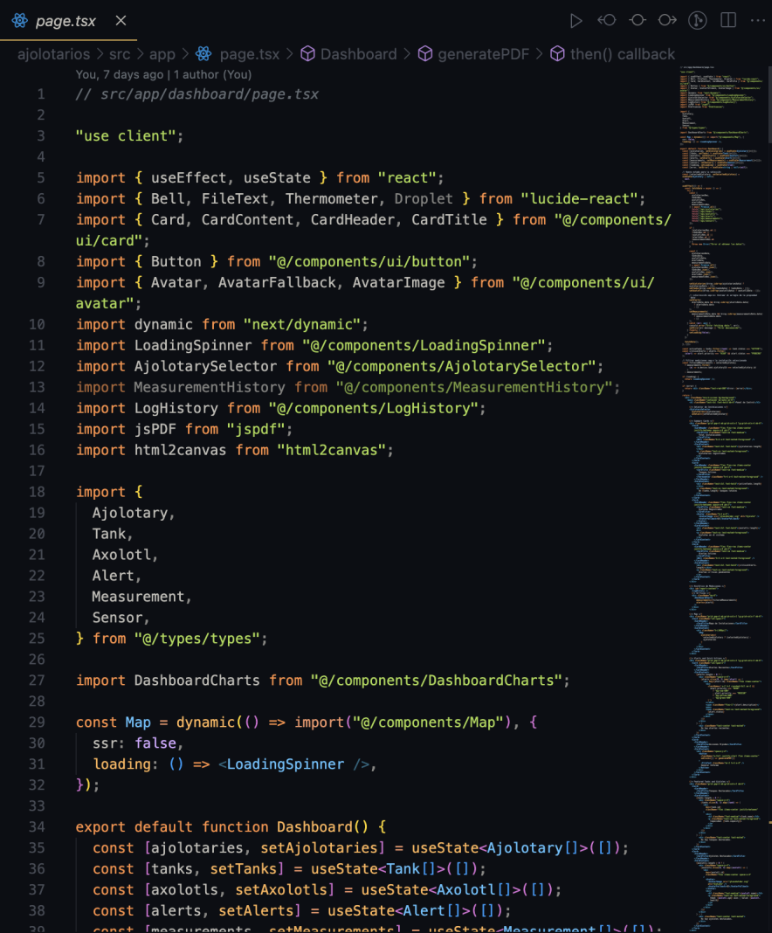
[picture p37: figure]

Figura 5. Vista de dashboard Fuente(s): Elaboración propía

### 7. Configuración inicial

Para configurar AjoloApp en un entorno local, primero es necesario clonar el repositorio del proyecto. Después, se deben instalar las dependencias utilizando el comando npm install. El archivo .env debe configurarse con variables como DATABASE_URL, que define la conexión a la base de datos, y NEXTAUTH_SECRET, utilizado para las sesiones de usuario. Una vez configurado el entorno, se deben ejecutar las migraciones de Prisma para crear las tablas en la base de datos.
Finalmente, el proyecto puede iniciarse con el comando npm | run | dev, que lo ejecuta
en http://localhost:3000. Esto es para el desarrollo en local, pero la aplicación puede ser desplegada en cualquier tipo de nube, pero se debe usar el comando npm run build

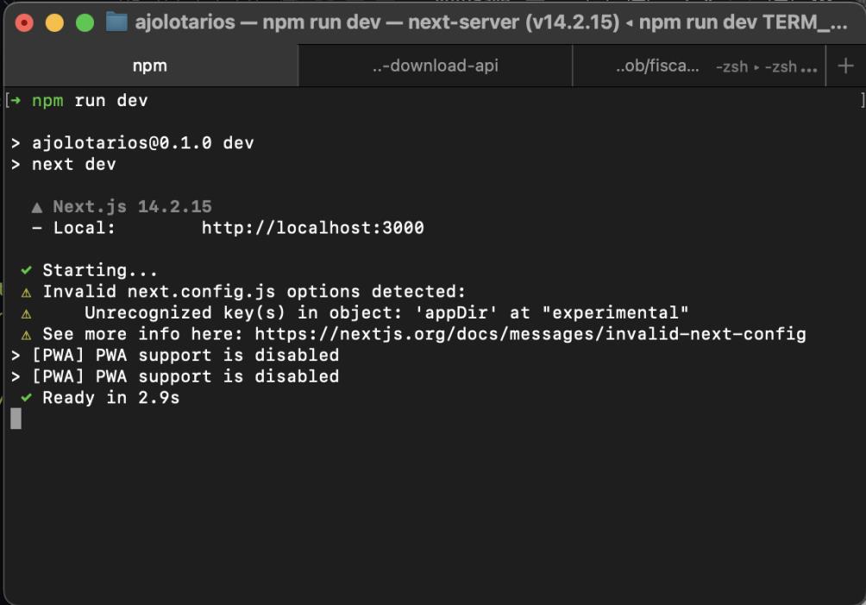
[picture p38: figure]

Figura 6. Correr proyecto en local Fuente(s): Elaboración propía

### 8. Gestión de Usuarios

Las integraciones clave incluyen el uso de Prisma para la base de datos, Tailwind CSS para los estilos y NextAuth para la autenticación. Las notificaciones se envían mediante las APIs de Telegram y WhatsApp, utilizando llamadas fetch. La generación de informes se realiza con jsPDF y html2canvas, que convierten el contenido HTML en documentos PDF descargables. Estas herramientas están configuradas para garantizar una integración fluida y eficiente en el sistema.

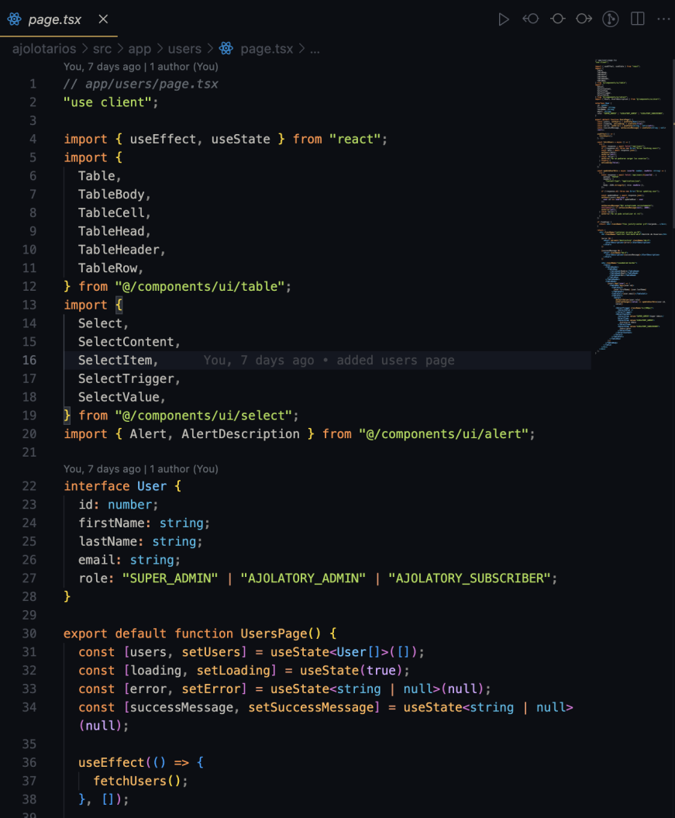
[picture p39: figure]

Figura 12. Componente de usuarios Fuente(s): Elaboración propía

### 9. Buenas prácticas

Para mantener la seguridad y eficiencia de AjoloApp, es fundamental seguir ciertas buenas prácticas. Las contraseñas deben estar encriptadas y las variables de entorno no deben exponerse en repositorios públicos. El código debe seguir un estilo consistente, utilizando herramientas como ESLint para detectar errores. Además, es importante modularizar las funcionalidades para facilitar futuras expansiones y utilizar paginación en consultas de grandes volúmenes de datos. Finalmente, se recomienda realizar pruebas unitarias y de integración para asegurar la estabilidad del sistema.

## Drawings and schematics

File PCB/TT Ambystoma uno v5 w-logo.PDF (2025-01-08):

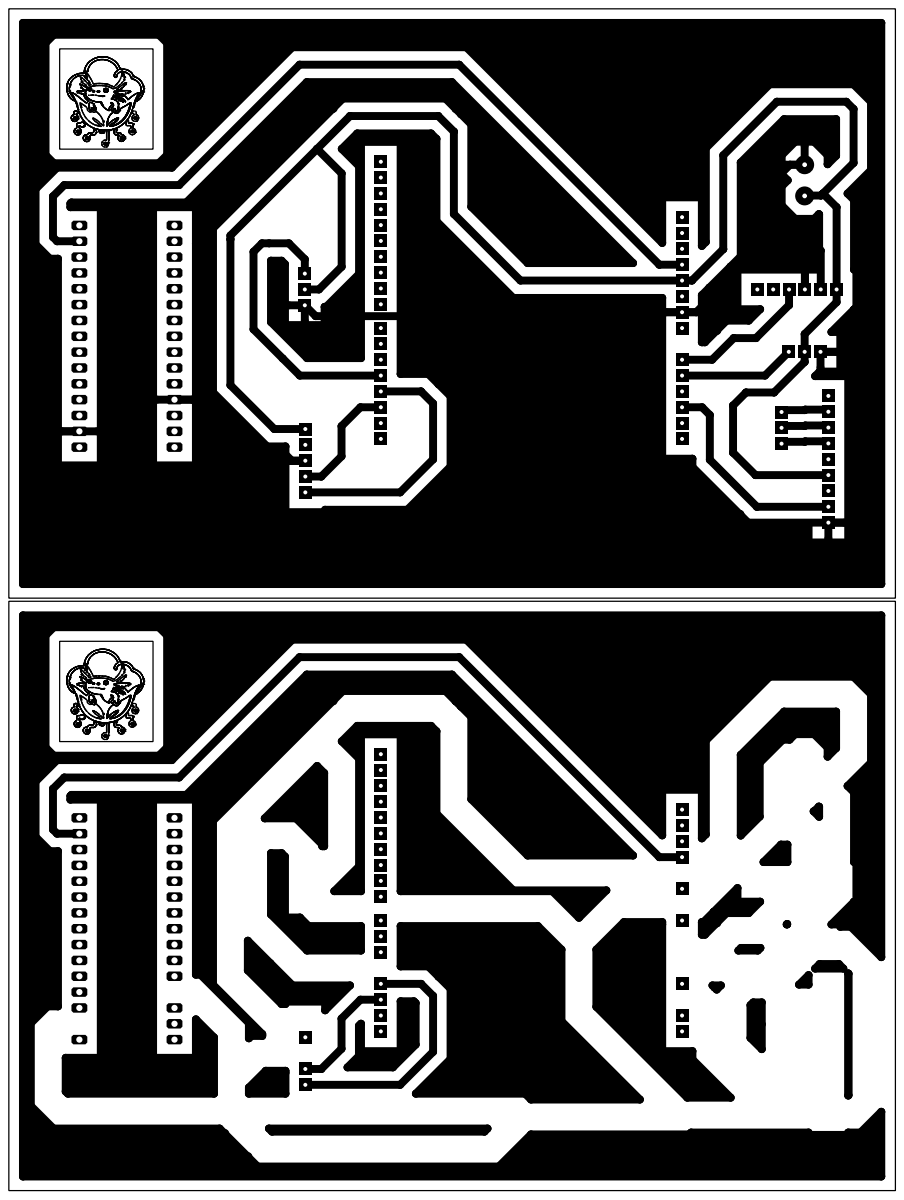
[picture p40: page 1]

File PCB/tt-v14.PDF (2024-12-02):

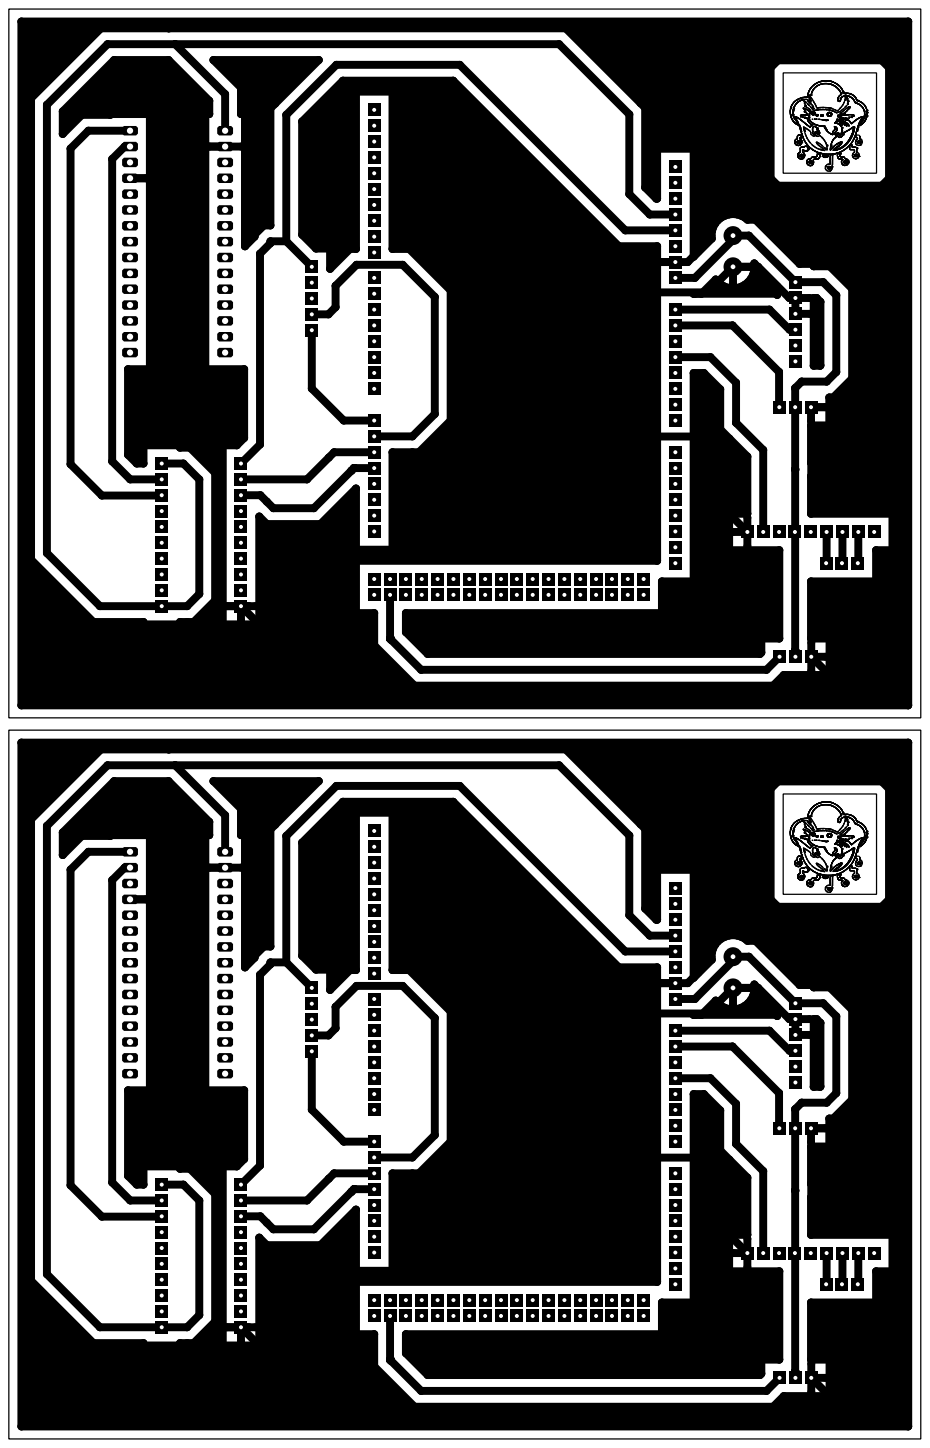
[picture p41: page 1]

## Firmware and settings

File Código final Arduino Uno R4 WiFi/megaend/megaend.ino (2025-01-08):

#include <Wire.h>
#include <OneWire.h>
#include <DallasTemperature.h>
#include "GravityTDS.h"
#include <EEPROM.h>
#include <ArduinoJson.h>
#include <WiFi.h>
#include <WiFiClient.h>
#include <WiFiUdp.h>
#include <NTPClient.h>
#include <SoftwareSerial.h>
#include <math.h> // Incluir math.h para funciones matemáticas

// Configuración de WiFi
const char* ssid = "Jeremy";
const char* password = "123456789";

// Configuración del servidor
const char* serverIP = "192.168.189.180";
const uint16_t serverPort = 8080;

// Pines de conexión
#define TdsSensorPin A1      // TDS
#define PHPin A0             // pH
#define TempSensorPin 4      // Temperatura OneWire (cambiado de 2 a 4)
#define TurbidityPin A3      // Turbidez

// Pines para SoftwareSerial del sensor de OD
#define OD_RX_PIN 2          // RX del sensor OD conectado al pin digital 2
#define OD_TX_PIN 3          // TX del sensor OD conectado al pin digital 3

// Inicializar SoftwareSerial para el sensor de OD
SoftwareSerial odSerial(OD_RX_PIN, OD_TX_PIN); // RX, TX

// Número de serie del dispositivo
const char* deviceSerialNumber = "DEV-AXOLOTL-01";

// Números de serie de los sensores
const char* sensorSerialNumbers[] = {
  "SEN-PH-001",
  "SEN-TEMP-002",
  "SEN-TDS-003",
  "SEN-DO-004",
  "SEN-TURB-005"
};

// Nombres de los parámetros
const char* parameterNames[] = {
  "pH",
  "Temperature",
  "TDS",
  "DissolvedOxygen",
  "Turbidity"
};

// Rangos aceptables
const float minPH = 6.00; // Umbral mínimo de pH
const float maxPH = 8.00; // Umbral máximo de pH
const float minTemp = 14.00;
const float maxTemp = 20.00;
const float minDO = 5.9; 
const float maxTDS = 1300.0; 
const float maxTurbidity = 15.00; 

// Variables globales para sensores
GravityTDS gravityTds;
OneWire oneWire(TempSensorPin);
DallasTemperature sensors(&oneWire);

float temperature = 25.0;
float tdsValue = 0.0;

// Constantes fijas para pH (sin calibración)
// Asegúrate de que estos valores sean correctos para tu sensor
const float m = -14.3;    // Pendiente de la recta (Y = mX + b)
const float b = 64.346;   // Intersección de la recta (Y = mX + b)

// Variables para promediar datos
const unsigned long sendInterval = 60000; // 10 minutos
unsigned long lastSendTime = 0;
int readingCount = 0;

// Sumas para promediar
float sumPH = 0;
float sumTemperature = 0;
float sumTDS = 0;
float sumDO = 0;
float sumTurbidity = 0;

// Flags de alerta
bool alertPH = false;
bool alertTemp = false;
bool alertTDS = false;
bool alertDO = false;
bool alertTurbidity = false;

// Control de mediciones
bool shouldMeasure = true;
bool takeImmediateMeasurement = false;

// Intervalos de medición
unsigned long lastMeasurementTime = 0;
const unsigned long measurementInterval = 1000; // 1 seg

// Alertas
bool alertSent = false;
unsigned long alertSentTime = 0;
const unsigned long alertRetryInterval = 180000; // 30 seg

// Tras una alerta, esperar 30 seg antes de volver a medir
bool waitAfterAlert = false;
unsigned long waitStartTime = 0;

// Modo calibración (solo para TDS y DO)
enum CalibrationMode { NONE, CAL_TDS, CAL_DO };
CalibrationMode calibrationMode = NONE;

// Factor calibración TDS
float tdsCalibrationFactor = 1.0;

// NTP
WiFiUDP ntpUDP;
NTPClient timeClient(ntpUDP, "pool.ntp.org", 0, 60000);

// WiFiClient para comunicación con el servidor
WiFiClient client;

// Funciones prototipo
float readTemperatureSensor();
float readPHSensor();
float readTurbiditySensor();
float readTDSSensor(float temperature);
float readDissolvedOxygen();
String buildJSON(bool isAlert);
void sendJSON(String jsonData);
void checkForCommands();
void processCommand(String commandData, bool fromSerialMonitor);
void calibrateDO();
void calibrateTDS(float calibrationValue);
void takeMeasurement();
void handleCalibration();
void handleAlertRetry();

// Función de setup
void setup() {
  // Iniciar comunicación serial para depuración
  Serial.begin(115200);
  delay(2000);

  // Iniciar SoftwareSerial para el sensor de OD
  odSerial.begin(9600);
  Serial.println("SoftwareSerial para OD iniciado en pines 2 (RX) y 3 (TX).");

  // Iniciar WiFi
  WiFi.begin(ssid, password);
  Serial.println("Conectando a WiFi...");
  while (WiFi.status() != WL_CONNECTED) {
    delay(500);
    Serial.print(".");
  }
  Serial.println("\nConectado a WiFi: " + WiFi.localIP().toString());

  timeClient.begin();
  timeClient.update();

  sensors.begin();
  gravityTds.setPin(TdsSensorPin);
  gravityTds.setAref(5.0);
  gravityTds.setAdcRange(1024);
  gravityTds.setKvalueAddress(0x08);
  gravityTds.begin();

  // Leer factor calibración TDS desde EEPROM
  EEPROM.get(10, tdsCalibrationFactor);
  if (isnan(tdsCalibrationFactor) || tdsCalibrationFactor == 0.0) {
    tdsCalibrationFactor = 1.0;
    Serial.println("No factor de calibración TDS en EEPROM. Usando valor por defecto.");
  } else {
    Serial.print("Factor calibración TDS: ");
    Serial.println(tdsCalibrationFactor, 4);
  }

  // Realizar primera medición inmediata
  takeImmediateMeasurement = true;

  Serial.println("Sistema iniciado. Esperando comandos...");
}

// Función de loop
void loop() {
  timeClient.update();
  checkForCommands();
  handleAlertRetry();

  // Si se ha recibido un comando "stop", no medir hasta "start" o "measure"
  if (!shouldMeasure) {
    return; // No medir ni hacer nada de sensores
  }

  // Si estamos esperando 30 seg después de alerta
  if (waitAfterAlert) {
    if (millis() - waitStartTime < 30000) {
      return; // Esperar 30 seg sin medir
    } else {
      waitAfterAlert = false;
    }
  }

  if (calibrationMode == NONE) {
    unsigned long currentMillis = millis();
    if (takeImmediateMeasurement) {
      takeImmediateMeasurement = false;
      takeMeasurement();
    } else if (currentMillis - lastMeasurementTime >= measurementInterval) {
      lastMeasurementTime = currentMillis;
      takeMeasurement();
    }
  } else {
    handleCalibration();
  }
}

// Funciones de lectura de sensores
float readTemperatureSensor() {
  sensors.requestTemperatures();
  float temp = sensors.getTempCByIndex(0);
  Serial.print("Temperatura: ");
  Serial.println(temp);
  return temp;
}

float readPHSensor() {
  long samples = 0;
  const int numSamples = 20; // Aumentar el número de muestras para mayor precisión
  for (int x = 0; x < numSamples; x++) {
    samples += analogRead(PHPin);
    delay(10);
  }
  float phVoltage = (samples / (float)numSamples) * (5.0 / 1024.0);
  float pHValue = m * phVoltage + b;
  Serial.print("pH: ");
  Serial.println(pHValue);
  return pHValue;
}

float readTurbiditySensor() {
  float voltCal = 1.10;   
  float varTemp = 0.0;
  float tempA25 = 0.0;
  float K = 0.0;
  float ntu = 0.0;
  int sensorValue = 0;

  float sumVal = 0.0;
  int rep = 30;
  for (int i = 0; i < rep; i++) {
    sensorValue = analogRead(TurbidityPin);
    float voltage = sensorValue * (5.0 / 1024.0);
    tempA25 = voltCal - varTemp;
    K = -865.68 * tempA25;
    ntu = (-865.68 * voltage) - K;
    if (ntu < 0) ntu = 0;
    sumVal += ntu;
    delay(10);
  }
  ntu = sumVal / rep;
  Serial.print("Turbidez (NTU): ");
  Serial.println(ntu);
  return ntu;
}

float readTDSSensor(float temperature) {
  gravityTds.setTemperature(temperature);
  gravityTds.update();
  float val = gravityTds.getTdsValue() * tdsCalibrationFactor;
  Serial.print("TDS: ");
  Serial.print(val, 0);
  Serial.println(" ppm");
  return val;
}

// Función simulada de lectura de DO (Onda Senoidal)
float readDissolvedOxygen() {
  static unsigned long lastUpdate = 0;
  static float angle = 0.0;
  unsigned long currentMillis = millis();
  
  // Actualizar el ángulo cada segundo
  if (currentMillis - lastUpdate >= 1000) { // 1 segundo
    angle += 0.05; // Velocidad de variación
    if (angle > 2 * PI) angle -= 2 * PI;
    lastUpdate = currentMillis;
  }
  
  // Mapear la onda senoidal (-1 a 1) al rango deseado (6.0 a 8.3)
  float DO = 7.15 + 1.15 * sin(angle); // Promedio 7.15, amplitud 1.15
  Serial.print("Simulated DO (mg/L): ");
  Serial.println(DO);
  return DO;
}

/*
// Alternativamente, si prefieres usar valores aleatorios, comenta la función anterior y usa la siguiente:
float readDissolvedOxygen() {
  // Inicializar la semilla aleatoria una vez
  static bool seedInitialized = false;
  if (!seedInitialized) {
    randomSeed(analogRead(0)); // Usar un pin analógico no conectado para la semilla
    seedInitialized = true;
  }

  // Generar un valor aleatorio entre 6.0 y 8.3
  float DO = 6.0 + ((float)rand() / RAND_MAX) * (8.3 - 6.0);
  Serial.print("Simulated DO (mg/L): ");
  Serial.println(DO);
  return DO;
}
*/

// Construir JSON
String buildJSON(bool isAlert) {
  StaticJsonDocument<1024> doc;
  doc["deviceSerialNumber"] = deviceSerialNumber;

  // Timestamp
  unsigned long epochTime = timeClient.getEpochTime();
  time_t rawTime = epochTime;
  struct tm * ti = gmtime(&rawTime);
  char timestamp[25];
  sprintf(timestamp, "%04d-%02d-%02dT%02d:%02d:%02dZ", ti->tm_year + 1900, ti->tm_mon + 1,
          ti->tm_mday, ti->tm_hour, ti->tm_min, ti->tm_sec);
  doc["timestamp"] = timestamp;

  JsonArray measurements = doc.createNestedArray("measurements");

  // pH
  JsonObject phObj = measurements.createNestedObject();
  phObj["sensorSerialNumber"] = sensorSerialNumbers[0];
  phObj["parameterName"] = parameterNames[0];
  phObj["value"] = sumPH / readingCount;
  phObj["alert"] = alertPH;

  // Temp
  JsonObject tempObj = measurements.createNestedObject();
  tempObj["sensorSerialNumber"] = sensorSerialNumbers[1];
  tempObj["parameterName"] = parameterNames[1];
  tempObj["value"] = sumTemperature / readingCount;
  tempObj["alert"] = alertTemp;

  // TDS
  JsonObject tdsObj = measurements.createNestedObject();
  tdsObj["sensorSerialNumber"] = sensorSerialNumbers[2];
  tdsObj["parameterName"] = parameterNames[2];
  tdsObj["value"] = sumTDS / readingCount;
  tdsObj["alert"] = alertTDS;

  // DO
  JsonObject doObj = measurements.createNestedObject();
  doObj["sensorSerialNumber"] = sensorSerialNumbers[3];
  doObj["parameterName"] = parameterNames[3];
  doObj["value"] = sumDO / readingCount;
  doObj["alert"] = alertDO;

  // Turbidez
  JsonObject turbObj = measurements.createNestedObject();
  turbObj["sensorSerialNumber"] = sensorSerialNumbers[4];
  turbObj["parameterName"] = parameterNames[4];
  turbObj["value"] = sumTurbidity / readingCount;
  turbObj["alert"] = alertTurbidity;

  String jsonData;
  serializeJson(doc, jsonData);
  return jsonData;
}

// Enviar JSON al servidor
void sendJSON(String jsonData) {
  if (WiFi.status() == WL_CONNECTED) {
    if (!client.connect(serverIP, serverPort)) {
      Serial.println("No se pudo conectar al servidor");
      return;
    }

    // Imprimir JSON en monitor serial antes de enviar
    Serial.println("JSON a enviar:");
    StaticJsonDocument<1024> debugDoc;
    DeserializationError error = deserializeJson(debugDoc, jsonData);
    if (!error) {
      serializeJsonPretty(debugDoc, Serial);
    } else {
      Serial.println("Error al deserializar para debug.");
      Serial.println(jsonData);
    }

    // Enviar el JSON
    client.println(jsonData);

    // Esperar respuesta (opcional)
    unsigned long t = millis() + 2000;
    while (millis() < t && client.connected()) {
      if (client.available()) {
        String response = client.readStringUntil('\n');
        Serial.print("Resp servidor: ");
        Serial.println(response);
        break;
      }
    }

    client.stop();
  } else {
    Serial.println("No conectado a WiFi");
  }
}

// Revisar y procesar comandos desde Serial
void checkForCommands() {
  if (Serial.available() > 0) {
    String commandData = Serial.readStringUntil('\n');
    processCommand(commandData, true);
  }
}

// Procesar comando
void processCommand(String commandData, bool fromSerialMonitor) {
  commandData.trim();

  // Si calibración en curso
  if (calibrationMode != NONE && fromSerialMonitor) {
    if (calibrationMode == CAL_TDS) {
      if (commandData.startsWith("cal:")) {
        float calValue = commandData.substring(4).toFloat();
        if (calValue > 0) calibrateTDS(calValue);
        else Serial.println("Valor calibración TDS inválido.");
      } else if (commandData.equalsIgnoreCase("exit")) {
        calibrationMode = NONE;
        Serial.println("Saliendo calibración TDS.");
      } else {
        Serial.println("Comando desconocido calibración TDS.");
      }
      return;
    } else if (calibrationMode == CAL_DO) {
      Serial.println("Calibración DO en proceso...");
      calibrationMode = NONE;
      return;
    }
  }

  // Comandos generales
  if (commandData.equalsIgnoreCase("Start")) {
    shouldMeasure = true;
    Serial.println("Iniciando mediciones.");
  } else if (commandData.equalsIgnoreCase("Stop")) {
    shouldMeasure = false;
    Serial.println("Deteniendo mediciones.");
  } else if (commandData.equalsIgnoreCase("Measure")) {
    shouldMeasure = true;
    takeImmediateMeasurement = true;
    Serial.println("Medición inmediata.");
  } else if (commandData.equalsIgnoreCase("calibrate")) {
    // Solo permitir calibración de TDS y DO
    Serial.println("Tipo de calibración: TDS, DO.");
    // Aquí podrías implementar opciones de calibración si es necesario
  } else if (commandData.equalsIgnoreCase("TDS") && calibrationMode == NONE) {
    if (fromSerialMonitor) {
      calibrationMode = CAL_TDS;
      Serial.println("Calibración TDS. 'cal:<valor>' o 'exit'.");
    } else {
      Serial.println("Comando 'TDS' requiere interacción manual.");
    }
  } else if (commandData.equalsIgnoreCase("DO") && calibrationMode == NONE) {
    if (fromSerialMonitor) {
      calibrateDO();
    } else {
      Serial.println("Comando 'DO' requiere interacción manual.");
    }
  } else if (commandData.equalsIgnoreCase("save")) {
    // No hay calibración pH que guardar
    Serial.println("No hay calibración para guardar.");
  } else {
    Serial.println("Comando desconocido.");
  }
}

// Calibrar DO
void calibrateDO() {
  Serial.println("Calibrando DO con aire...");
  calibrationMode = CAL_DO;
  shouldMeasure = false;

  // Enviar comando calibración OD a través de SoftwareSerial (adaptar según sensor)
  odSerial.print("Cal\r");
  unsigned long t = millis() + 2000;
  String response = "";
  while (millis() < t) {
    if (odSerial.available()) {
      char c = odSerial.read();
      if (c == '\r') break;
      response += c;
    }
  }

  if (response.length() > 0) {
    Serial.print("Resp calibración DO: ");
    Serial.println(response);
    if (response.indexOf("*OK") != -1 || response.indexOf("OK") != -1) {
      Serial.println("Calibración DO exitosa.");
    } else {
      Serial.println("Error calibración DO.");
    }
  } else {
    Serial.println("No respuesta sensor DO.");
  }

  calibrationMode = NONE;
}

// Calibrar TDS
void calibrateTDS(float calibrationValue) {
  Serial.print("Calibrando TDS a ");
  Serial.print(calibrationValue);
  Serial.println(" ppm.");
  gravityTds.setTemperature(25.0);
  gravityTds.update();
  float tdsCal = gravityTds.getTdsValue();
  tdsCalibrationFactor = calibrationValue / tdsCal;
  Serial.print("Factor TDS: ");
  Serial.println(tdsCalibrationFactor, 4);
  EEPROM.put(10, tdsCalibrationFactor);
  Serial.println("Factor TDS guardado.");
  calibrationMode = NONE;
}

// Tomar medición
void takeMeasurement() {
  Serial.println("Tomando medición...");
  temperature = readTemperatureSensor();
  float pH = readPHSensor();
  tdsValue = readTDSSensor(temperature);
  float doValue = readDissolvedOxygen();
  float turbidity = readTurbiditySensor();

  sumTemperature += temperature;
  sumPH += pH;
  sumTDS += tdsValue;
  sumDO += doValue;
  sumTurbidity += turbidity;
  readingCount++;

  bool outOfRange = false;

  // **Desactivar alertas de pH**
  alertPH = false; // Siempre false

  // Actualizar la lógica de alerta para otros parámetros
  alertTemp = (temperature < minTemp || temperature > maxTemp);
  alertDO = (doValue < minDO); // Esta condición nunca será verdadera con la simulación
  alertTurbidity = (turbidity > maxTurbidity);
  alertTDS = (tdsValue > maxTDS);

  // Puedes optar por excluir alertPH de la siguiente línea si lo prefieres:
  // bool outOfRange = alertTemp || alertTDS || alertDO || alertTurbidity;
  
  // O mantener alertPH en la evaluación, pero siempre será false
  outOfRange = alertPH || alertTemp || alertTDS || alertDO || alertTurbidity;

  if (outOfRange) {
    Serial.println("Alerta detectada en parámetros.");
    if (!alertSent) {
      String jsonData = buildJSON(true);
      sendJSON(jsonData);
      alertSent = true;
      alertSentTime = millis();
      // Esperar 30 seg antes de próxima medición
      waitAfterAlert = true;
      waitStartTime = millis();
    }
  } else {
    alertSent = false;
    alertSentTime = 0;
  }

  if (millis() - lastSendTime >= sendInterval) {
    if (readingCount > 0) {
      String jsonData = buildJSON(false);
      sendJSON(jsonData);
      sumTemperature = sumPH = sumTDS = sumDO = sumTurbidity = 0;
      readingCount = 0;
      lastSendTime = millis();
    }
  }
}

// Reintentos de alerta
void handleAlertRetry() {
  if (alertSent && (millis() - alertSentTime >= alertRetryInterval)) {
    Serial.println("Reintentando medición tras alerta...");
    alertSent = false;
    takeImmediateMeasurement = true;
  }
}

// Manejar calibración en proceso (solo TDS y DO)
void handleCalibration() {
  // Actualmente, no hay acciones adicionales necesarias
}

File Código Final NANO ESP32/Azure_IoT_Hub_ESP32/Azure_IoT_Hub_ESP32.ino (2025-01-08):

#include <WiFi.h>
#include <WiFiClient.h>
#include <WiFiServer.h>
#include <mqtt_client.h>
#include <ArduinoJson.h>
#include <time.h>

// Librerías de Azure
#include <az_core.h>
#include <az_iot.h>
#include <az_iot_hub_client.h>
#include <az_iot_provisioning_client.h>
#include <az_span.h>
#include <az_json.h>
#include <azure_ca.h>

// Configuración IoT
#include "iot_configs.h"
#include "AzIoTSasToken.h"
#include "SerialLogger.h"

// Definiciones y configuraciones
#define AZURE_SDK_CLIENT_USER_AGENT "c%2F" AZ_SDK_VERSION_STRING "(ard;esp32)"
#define sizeofarray(a) (sizeof(a) / sizeof(a[0]))
#define NTP_SERVERS "pool.ntp.org", "time.nist.gov"
#define MQTT_QOS1 1
#define DO_NOT_RETAIN_MSG 0
#define SAS_TOKEN_DURATION_IN_MINUTES 60
#define UNIX_TIME_NOV_13_2017 1510592825
#define PST_TIME_ZONE -8
#define PST_TIME_ZONE_DAYLIGHT_SAVINGS_DIFF 1
#define GMT_OFFSET_SECS (PST_TIME_ZONE * 3600)
#define GMT_OFFSET_SECS_DST ((PST_TIME_ZONE + PST_TIME_ZONE_DAYLIGHT_SAVINGS_DIFF) * 3600)
#define TELEMETRY_FREQUENCY_MILLISECS 600000 // 10 minutos

// Configuración de WiFi y Azure IoT
static const char* ssid = IOT_CONFIG_WIFI_SSID;
static const char* password = IOT_CONFIG_WIFI_PASSWORD;
static const char* host = IOT_CONFIG_IOTHUB_FQDN;
static const char* mqtt_broker_uri = "mqtts://" IOT_CONFIG_IOTHUB_FQDN;
static const char* device_id = IOT_CONFIG_DEVICE_ID;
static const int mqtt_port = AZ_IOT_DEFAULT_MQTT_CONNECT_PORT;

// Manejo de MQTT y Azure IoT
static esp_mqtt_client_handle_t mqtt_client;
static az_iot_hub_client client;
static char mqtt_client_id[128];
static char mqtt_username[128];
static char mqtt_password[200];
static uint8_t sas_signature_buffer[256];
static char telemetry_topic[128];
static String telemetry_payload = "{}";

// Buffer para datos entrantes
#define INCOMING_DATA_BUFFER_SIZE 2048
static char incoming_data[INCOMING_DATA_BUFFER_SIZE];

// Servidor WiFi
WiFiServer wifiServer(8080); // Puerto del servidor

// Variables de tiempo
const char* ntpServer = "pool.ntp.org";
const long  gmtOffset_sec = 0;
const int   daylightOffset_sec = 0;

// Variable para almacenar el cliente conectado (Uno R4 WiFi)
WiFiClient activeClient;
bool clientConnected = false;

// SAS Token
#ifndef IOT_CONFIG_USE_X509_CERT
static AzIoTSasToken sasToken(
    &client,
    AZ_SPAN_FROM_STR(IOT_CONFIG_DEVICE_KEY),
    AZ_SPAN_FROM_BUFFER(sas_signature_buffer),
    AZ_SPAN_FROM_BUFFER(mqtt_password));
#endif

// Función para reenviar JSON al Arduino Uno R4 WiFi
static void sendJSONToUno(const String& json) {
  if (clientConnected && activeClient.connected()) {
    Serial.println("Enviando JSON de respuesta al Arduino Uno R4 WiFi:");
    Serial.println(json);
    activeClient.println(json);
  } else {
    Serial.println("No hay cliente conectado para enviar JSON de vuelta.");
  }
}

static void connectToWiFi()
{
  Serial.println("Conectando a WiFi...");
  WiFi.mode(WIFI_STA);
  WiFi.disconnect();
  delay(100);
  WiFi.begin(ssid, password);
  while (WiFi.status() != WL_CONNECTED) {
    delay(500);
    Serial.print(".");
  }

  Serial.println("");
  Serial.println("WiFi conectado. IP: " + WiFi.localIP().toString());
}

static void initializeTime()
{
  Serial.println("Configurando tiempo via NTP");
  configTime(gmtOffset_sec, daylightOffset_sec, ntpServer);
  time_t now = time(nullptr);
  while (now < UNIX_TIME_NOV_13_2017) {
    delay(500);
    Serial.print(".");
    now = time(nullptr);
  }
  Serial.println("");
  Serial.println("Tiempo inicializado!");
}

static void generateTelemetryPayload(String jsonData)
{
  StaticJsonDocument<2048> doc;
  DeserializationError error = deserializeJson(doc, jsonData);

  if (error) {
    Serial.print("Error al parsear JSON: ");
    Serial.println(error.c_str());
    return;
  }

  // Obtener timestamp actual
  time_t now = time(NULL);
  struct tm* timeinfo = gmtime(&now);
  char timestamp[64];
  strftime(timestamp, sizeof(timestamp), "%Y-%m-%dT%H:%M:%SZ", timeinfo);

  doc["timestamp"] = timestamp;

  String modifiedJson;
  serializeJson(doc, modifiedJson);
  telemetry_payload = modifiedJson;
}

static void sendTelemetryToAzure()
{
  Serial.println("Enviando telemetría a Azure IoT Hub...");

  if (az_result_failed(az_iot_hub_client_telemetry_get_publish_topic(
          &client, NULL, telemetry_topic, sizeof(telemetry_topic), NULL))) {
    Serial.println("Error al obtener tópico de telemetría");
    return;
  }

  int msg_id = esp_mqtt_client_publish(
      mqtt_client,
      telemetry_topic,
      telemetry_payload.c_str(),
      telemetry_payload.length(),
      MQTT_QOS1,
      DO_NOT_RETAIN_MSG);

  if (msg_id == 0) {
    Serial.println("Error al publicar mensaje");
  } else {
    Serial.println("Mensaje publicado exitosamente a Azure IoT Hub");
  }
}

// Manejo de eventos MQTT
#if defined(ESP_ARDUINO_VERSION_MAJOR) && ESP_ARDUINO_VERSION_MAJOR >= 3
static void mqtt_event_handler(void *handler_args, esp_event_base_t base, int32_t event_id, void *event_data)
{
  (void)handler_args;
  (void)base;
  (void)event_id;

  esp_mqtt_event_handle_t event = (esp_mqtt_event_handle_t)event_data;

  switch (event->event_id) {
    case MQTT_EVENT_ERROR:
      Serial.println("MQTT_EVENT_ERROR");
      break;
    case MQTT_EVENT_CONNECTED:
      Serial.println("MQTT_EVENT_CONNECTED");
      {
        int r = esp_mqtt_client_subscribe(mqtt_client, AZ_IOT_HUB_CLIENT_C2D_SUBSCRIBE_TOPIC, 1);
        if (r == -1) {
          Serial.println("No se pudo suscribir a mensajes C2D.");
        } else {
          Serial.println("Suscrito a mensajes C2D; ID: " + String(r));
        }
      }
      break;
    case MQTT_EVENT_DISCONNECTED:
      Serial.println("MQTT_EVENT_DISCONNECTED");
      break;
    case MQTT_EVENT_SUBSCRIBED:
      Serial.println("MQTT_EVENT_SUBSCRIBED");
      break;
    case MQTT_EVENT_UNSUBSCRIBED:
      Serial.println("MQTT_EVENT_UNSUBSCRIBED");
      break;
    case MQTT_EVENT_PUBLISHED:
      Serial.println("MQTT_EVENT_PUBLISHED");
      break;
    case MQTT_EVENT_DATA: {
      Serial.println("MQTT_EVENT_DATA (Mensaje C2D recibido de Azure)");
      // Extraer el mensaje
      String c2dMessage;
      c2dMessage.reserve(event->data_len);
      for (int i = 0; i < event->data_len; i++) {
        c2dMessage += event->data[i];
      }
      Serial.println("Mensaje C2D: " + c2dMessage);

      // Intentar parsear el mensaje C2D como JSON y reenviarlo al Arduino Uno R4 WiFi
      if (clientConnected && activeClient.connected()) {
        Serial.println("Reenviando mensaje C2D al Arduino Uno R4 WiFi...");
        sendJSONToUno(c2dMessage);
      } else {
        Serial.println("No hay cliente UNO R4 WIFI conectado para reenviar C2D.");
      }
    } break;
    case MQTT_EVENT_BEFORE_CONNECT:
      Serial.println("MQTT_EVENT_BEFORE_CONNECT");
      break;
    default:
      Serial.println("MQTT_EVENT_UNKNOWN");
      break;
  }
}
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

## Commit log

2024-02-11 Subida inicial de archivos
    Archivos que tenemos como precedentes dados por la directora del TT así como algunos elaborados para la calibración y uso de los sensores de Ph, TSS, TDS y temperatura
2024-02-11 Unión de sensores
    Avance del archivo para la unión de los sensores en Arduino
2024-02-12 Sensores web
    Unión de los sensores con un modulo WiFi integrado
2024-02-12 Bibliotecas, oxigeno disuelto, union y web
    Inclusión de las bibliotecas de Dallas Temperature y One Wire, se añade también el código para el sensor de oxigeno disuelto y también el código para todos los sensores para verse y exponerse en inte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
2024-02-12 HTML, TSS
    Se incluye la lectura de turbidez y se sirve un HTML sencillo donde se leen los datos, se incluye un HTML por si después se puede leer desde un archivo externo el HTML, aunque posteriormente se usara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
2024-02-12 Conexión
    Se arreglo que los datos fueran estaticos a dinámicos para siempre mandarlo a la página web y se añadio la libreria de gravity TDS en .zip
    [sensores_web_basico.ino]
2024-02-12 Conexión a internet y vista en serial monitor
    Se da el SSID y el PASSWORD para la conexión a internet donde se puede ver la página así como también se pueden ver los datos en el serial monitor y la dirección IP para visualizar la página
2024-02-12 Escribir en el serial monitor
    Se escribe todo lo que los sensores captan en el serial monitor del arduino
2024-02-28 PCB y actualización de comentarios
    Creación de PCB para las placas de control y la conexión a arduino además de incluir el esp01 y su imagen de referencia
2024-02-29 Implementación de flask
    Avances para mandar datos de sensores a página web a través de flask
2024-03-01 Añadimiento de datasheet
    Sensor de Ph y temperatura
2024-03-01 Datasheet de TDS
2024-03-01 Datasheet de oxigeno disuelto y TSS
2024-03-01 Creación del entorno virtual
    Entorno virtual para flask
    [pyvenv.cfg]
2024-03-12 Inclusión de la nueva versión del PCB
2024-03-12 Comentarios y añadidos a PCB
    Se introducen comentarios de como debe ir conectada cada placa tanto dentro del esquemático como ya en la placa realizada
2024-03-12 PCB V3
    Versión 3 del PCB con añadidos de LED para indicar el recibimiento de datos por parte de los sensores y logo en el PCB
2024-03-12 PCB V.3 Con y sin logo
    Hubo error en tratar de abrir la versión 3 con el logo, se incluye la versión 3 con y sin logo
    [Logo vectorizado.dxf]
2024-03-14 Organización de archivos e incluso de código para usar con flask
    [Logo vectorizado.dxf]
2024-03-15 Organización de los archivos
    [Logo vectorizado.dxf]
2024-03-19 Protocolo y PCB
    Se añaden las copias de seguridad del PCB generadas por proteus así como también se añaden comentarios al PCB para una mejor comprensión de conexión, finalmente, se añade el protocolo realizado para 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
2024-05-12 Cambio grande 1
    Dentro de estos cambios se realizo una prueba unitaria y útil del sensor de pH creando el código para el Arduino como para el ESP-01 funcionando de igual manera a que sirva desde flask en un ambiente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
    [DS18B20 temperature.fzz, Diagrama TT.fzz, esp32-turbidity-fritzing.fzz]
2024-05-22 Pruebas unitarias y organización de las carpetas
    Se crearon las pruebas unitarias para cada sensor y dispositivo utilizado, se incluyen los esquemáticos para la prueba unitaria de cada sensor. Se modificaron las carpetas de los sensores para una me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
    [Conexión ESP01, PRUEBA 1.fzz, Prueba unitaria Esquemático.fzz, Prueba unitaria OD.fzz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]
2024-06-16 Presentación de TT1
    Se sube la presentación y todas las imágenes usadas en la presentación además de incluir las carpetas
    [Arduino Mega 2560 - 3mf.3mf]
2024-06-17 Nuevo PCB y primera versión de reporte técnico
    Se añaden los archivos de la nueva PCB donde ya se usa el arduino mega para un diseño más sencillo y se incluye el reporte técnico realizado a la fecha de 16-06-2024
2024-06-24 cambios menores en el PCB
2024-11-10 Inclusión de PCB y Arduino
2024-11-17 Camvio de carpetas y pcb final
    [pyvenv.cfg]
2024-11-20 nueva pcb y cambio de tds
2024-11-22 Bibliotecas para conexión de Azure
2024-11-22 Códigos de arduino con conexión a internet
2024-11-24 Cambio PCB y último código arduino uno wifi
2024-12-02 Cartel para el congreso y última versión del PCB con Arduino Mega y Arduino NANO ESP32
2025-01-08 Final pt1
    Últimas modificaciones al proyecto
    [pyvenv.cfg, r4.fzz]
2025-01-08 Código final NANO ESP32
2025-01-08 Código Final Arduino Uno R4 WiFi
2025-01-08 Pruebas Unitaria Arduino Mega
2025-01-08 Arduino Uno DO
    Prueba Unitaria para el sensor de Oxigeno Disuelto en un Arduino Uno tanto R4 WiFi como versión normal
2025-01-08 Pruebas con cada sensor
    Se incluyen las carpeta con todas las pruebas unitarias de cada sensor
2025-01-08 Más pruebas unitarias de sensores
2025-01-08 Pruebas de componente
    [pyvenv.cfg]
2025-01-08 Carpeta Final de Entregables CATT
